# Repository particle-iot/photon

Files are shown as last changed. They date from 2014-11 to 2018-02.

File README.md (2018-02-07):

# Photon

The Photon is a tiny WiFi development kit based around USI's WM-N-BM-09 module. This module is a combination of Broadcom's BCM43362 WiFi radio and a STM32F205G microcontroller.

The Photon has a similar footprint and is as close to drop-in compatible as possible with the Spark Core.

### Some highlights of the USI module:

 1. IEEE 802.11b/g/n
 2. Soft AP mode - read smooth WiFi setup process
 3. STM32F205G
 	- 1 MB Flash
 	- 128KB RAM
 	- 120 MHz clock
 4. Measures 12mm x 11mm x 1.3mm

Compared to the Spark Core, the Photon introduces some additional hardware features and changes:

 1. Pin 3V3* is now replaced with VBAT. This pin can be used to power the internal RTC, backup registers and SRAM when the module is put in standby mode.
 2. Pins D1 and D2 can also be used for CAN communication (TX and RX respectively).
 3. Pin A3 now features a DAC (channel 2)
 4. Pin A6 is changed to DAC and exposes a DAC (channel 1).
 5. Pin A7 is changed to WKP (Wakeup). This pin can be used as a standard GPIO, ADC input, PWM or to WAKEUP (rising edge) the module from sleep/standby modes.

A detailed description of the pin mapping can be found in the pin-mapping folder of this repository.
* Sheet 1: Overview of the pin-out.
* Sheet 2: Detailed description of USI module pin-out and its internal mapping to the microcontroller and WiFi radio.

### Pin Descriptions:
- **VIN:** This is the power supply pin to the Photon with a voltage range of 3.6 to 5.5VDC (internally regulated down to 3.3VDC). When the Photon is powered via its USB port, this pin will *ouput* a voltage of approximately 4.7VDC. Why 4.7 and not 5? Well, the actual voltage will be the USB voltage, which is normally 5, minus the forward voltage drop (0.3V) of the protection diode.
- **RST:** This is an active-low reset pin for the Photon.
- **VBAT:** Supply to the internal RTC, backup registers and SRAM (1.8 to 3.3VDC).
- **3V3:** This pin is the output of the on-board regulator and is internally connected to the VDD of the WiFi module. When powering the Photon via VIN or the USB port, this pin will *output* a voltage of 3.3VDC. This pin can also be used to power the Photon directly (max input 3.3VDC). **NOTE:** When powering the Photon via this pin, do not put power on the VIN pin.
- **WKP:** This is an active-high input that allows you to wakeup the module from sleep/deep sleep modes. When not used as a WAKEUP, this pin can also be used as a digital GPIO, ADC input or PWM.
- **D0 - D7:** These are _digital only_ GPIO pins.
- **A0 - A5:** These can be used as digital GPIOs or as ADC inputs.
- **DAC:** This pin can be used as a digital GPIO, ADC input or as a DAC ouput.
- **RX:** Primarily used as UART RX, but can also be used as a digital GPIO, ADC input or PWM.
- **TX:** Primarily used as UART TX, but can also be used as a digital GPIO, ADC input or PWM.

Please review the spreadsheet under the pin-mapping folder to better understand the alternate functions of the GPIO pins.

### Eagle (schematic and pcb layout):
Under the `eagle` folder, you'll find the history of Photon designs.
 1. **cam-drc:** Contains CAM Jobs (for creating gerbers) and DRC (Design Rule) files.
 2. **photon_v001:** The initial photon design.  This version of the design uses the same dimensions as the Spark Core and provides through-hole headers for mounting.
 3. **photon_v010:** Several versions later, numerous tweaks and additions to the schematic, smaller less blinding RGB LED, aligned D7 LED with D7 pin, new SMPS voltage regulator, castellated and non-castellated have been merged, new slightly larger higher gain antenna, Bluetooth Co-existance pins are broken out to pads for a 1.27mm pitch (0.050") connector, pads on the bottom side of the board were added for the RGB LED, and MODE button connections and are centered on the 0.1" grid, and RF switch for software selection of u.FL vs Chip Ant. RF Test board's for versions are included to make tuning of matching components in RF stage easier. There is a second Photon design here with antenna scooted to the left 0.027" to give more clearance between D0 pin and antenna.  C1 in Pi filter was removed to make room for this tighter layout.
 4. **photon_v019:** Several more versions later, numerous tweaks and additions to the schematic, WM-N-BM-09 soldermask updated, added some GND vias, MODE button label changed to SETUP, increased width of top and bottom (short) sides of PCB 20 mils to allow for v-score (overall board height is now 1.44"), SETUP and RESET buttons and RGB led are not centered on the 0.1" grid anymore but they are all still inline with each other, RF switch was changed to a much smaller 1mm version, 0201 dc blocking capacitors added to all RF ports, Pi filter was tuned to match antenna to 50 ohm impedance, half of the pads on the bottom were enlarged to 60 mils square, added fabrication spec.

# License

Designed by Particle. Distributed under a Creative Commons Attribution, Share-Alike license.
Development kits based on this product should be distributed under a similar license.
Commercial products using the Photon as a reference design need not comply with this license; further questions can be sent to hello@particle.io.
Check license.txt for more information.

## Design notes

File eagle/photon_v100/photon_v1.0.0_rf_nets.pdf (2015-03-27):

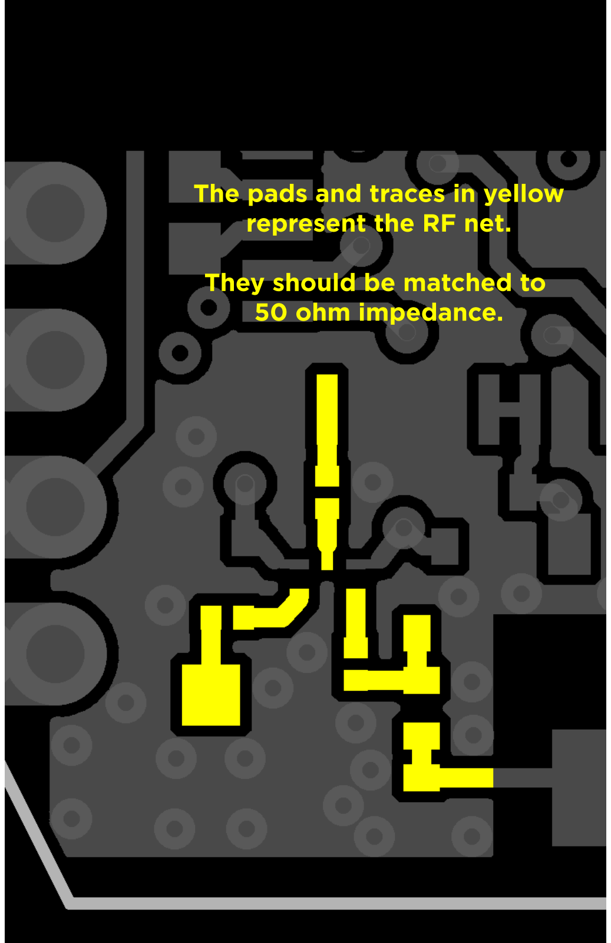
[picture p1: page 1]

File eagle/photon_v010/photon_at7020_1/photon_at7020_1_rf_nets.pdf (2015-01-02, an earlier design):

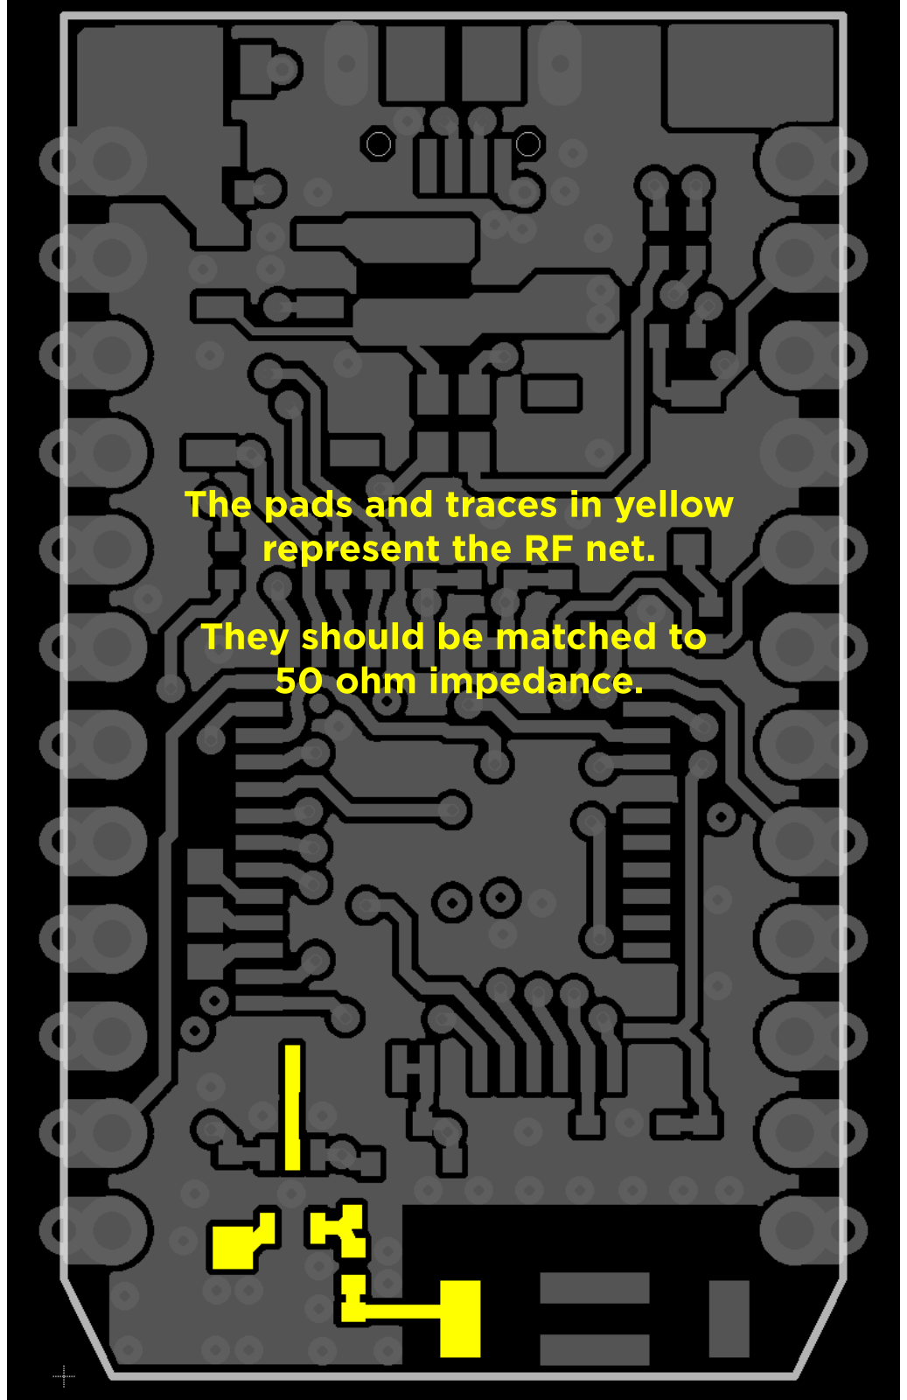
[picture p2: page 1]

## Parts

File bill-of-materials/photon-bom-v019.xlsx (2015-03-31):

Spark |  | Photon
BOM Version |  | v0.1.9
Qty | Device | Minimum Specification | Package/Case | Part Designator | MFG. | MFG. PN
1 | ANTENNA | 2.4GHz, Ceramic | 5.0mm × 2.0mm x 2.6mm | ANT1 | Advanced Ceramic X Johnason | AT7020-E3R0HBA 2450AT43B100E
2 | CERAMIC CAPACITOR | 22uF, Ceramic, 6.3V, 10%, X5R | 0603 | C4, C5 | Samsung | CL10A226MQ8NRNC
6 | CERAMIC CAPACITOR | 0.1uF, Ceramic, 6.3V, 10%, X5R | 0402 | C6, C7, C8, C10, C12, C16 | RongFu | 0402B104K01A
2 | CERAMIC CAPACITOR | 100pF, Ceramic, 6.3V, 10%, X5R | 0402 | C2, C3 | Fenghua | 0402CG101J500NT
4 | CERAMIC CAPACITOR | 10uF, Ceramic, 6.3V, 10%, X5R | 0603 | C9, C11, C13, C15 | Sumsung | CL10A106MQ8NNNC
3 | CERAMIC CAPACITOR (RF) | 10pF, Ceramic, 6.3V, 10%, X5R | 0402 | C16, C17, C18 | Murata | GJM1555C1HR80BB01D
1 | CONNECTOR | USB Micro-B with tabs and slots | USB-MICROB | X1 | Kaweei | CMCUSB-5BFM2G-01-D
1 | CONNECTOR | uFL Connector | SMD | X2 | Kaweei | P1163-0140R
2 | HEADER | Single String, 1.2" Mating Length | 0.1" 12-pin | JP1, JP2 | Kaweei | CP25411-12G-S116-A
1 | DIODE | Diode, Schottky, 30V, 3A | DO-220AA | D1 | Vishay | SS3P3-M3/84A
1 | DIODE (LED) | Blue, SMD | 0603 | LED1 | Everlight | 19-217/BHC-ZL1M2RY/3T
1 | DIODE (LED) | LED RGB, Common Anode, Diffused, SMD | 4-PLCC (2.0mm x 2.0mm) | LED2 | Cree | CLVBA-FKA-CAEDH8BBB7A363
1 | INDUCTOR | 2.2uH, 1.5A | 3mm x 3mm | L5 | Taiyo Yuden | NR3015T2R2M
1 | INDUCTOR (RF) | 3.9nH, RF inductor | 0402 | L4 | Johanson | L-07C3N9SV6T
1 | INDUCTOR (RF) | 4.7nH, RF inductor | 0402 | L1 | Johanson | L-07C4N7SV6T
1 | INDUCTOR (RF) | 6.8nH, RF inductor | 0402 | L3 | Johanson | L-07C6N8JV6T
1 | WI-FI + MCU | Broadcom Wi-FI + STM32 MCU | Custom USI SMD | U1 | USI | WM-N-BM-09
1 | RF SWITCH | RF Switch SPDT | UQFN-6 (1x1mm) | U3 | Skyworks | SKY13350-385LF
1 | POWER REGULATOR | 3.3V,1.5MHz, 600mA, High Efficiency PWM Step-Down DC/DC Converter | SOT23-5 | U2 | Richtek | RT8008-33GB
1 | RESISTOR | 100K, 5% | 0402 | R4 | Fenghua | RC-02W104FT
2 | RESISTOR | 22R, 5% | 0402 | R5, R6 | Fenghua | RC-02W220JT
1 | RESISTOR | 10K, 5% | 0402 | R8 | Fenghua | RC-02W103JT
4 | RESISTOR | 1K, 5% | 0402 | R9, R10, R11, R12 | Fenghua | RC-02W102JT
2 | SWITCH | Button, 160gf | 3.6mm x 3.1mm | SETUP, RESET | Haoyu | TS-1185A-C

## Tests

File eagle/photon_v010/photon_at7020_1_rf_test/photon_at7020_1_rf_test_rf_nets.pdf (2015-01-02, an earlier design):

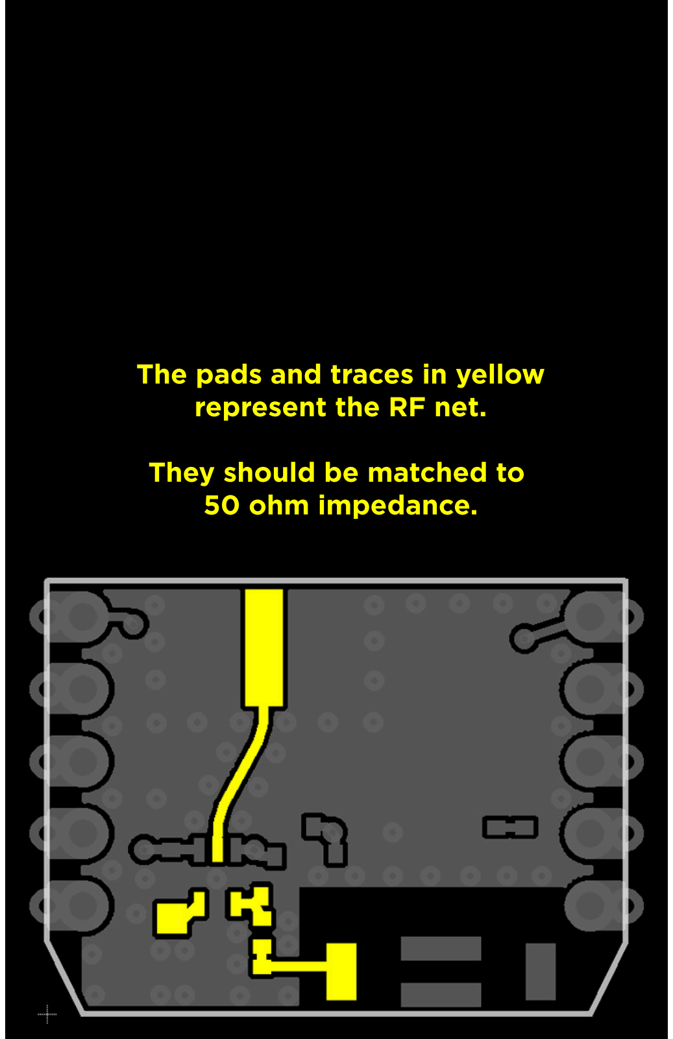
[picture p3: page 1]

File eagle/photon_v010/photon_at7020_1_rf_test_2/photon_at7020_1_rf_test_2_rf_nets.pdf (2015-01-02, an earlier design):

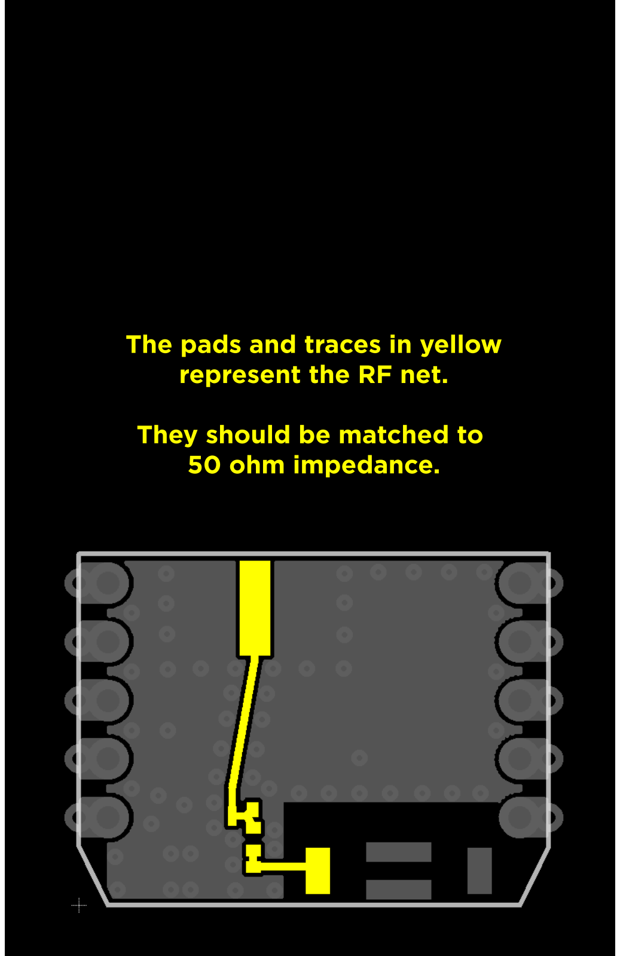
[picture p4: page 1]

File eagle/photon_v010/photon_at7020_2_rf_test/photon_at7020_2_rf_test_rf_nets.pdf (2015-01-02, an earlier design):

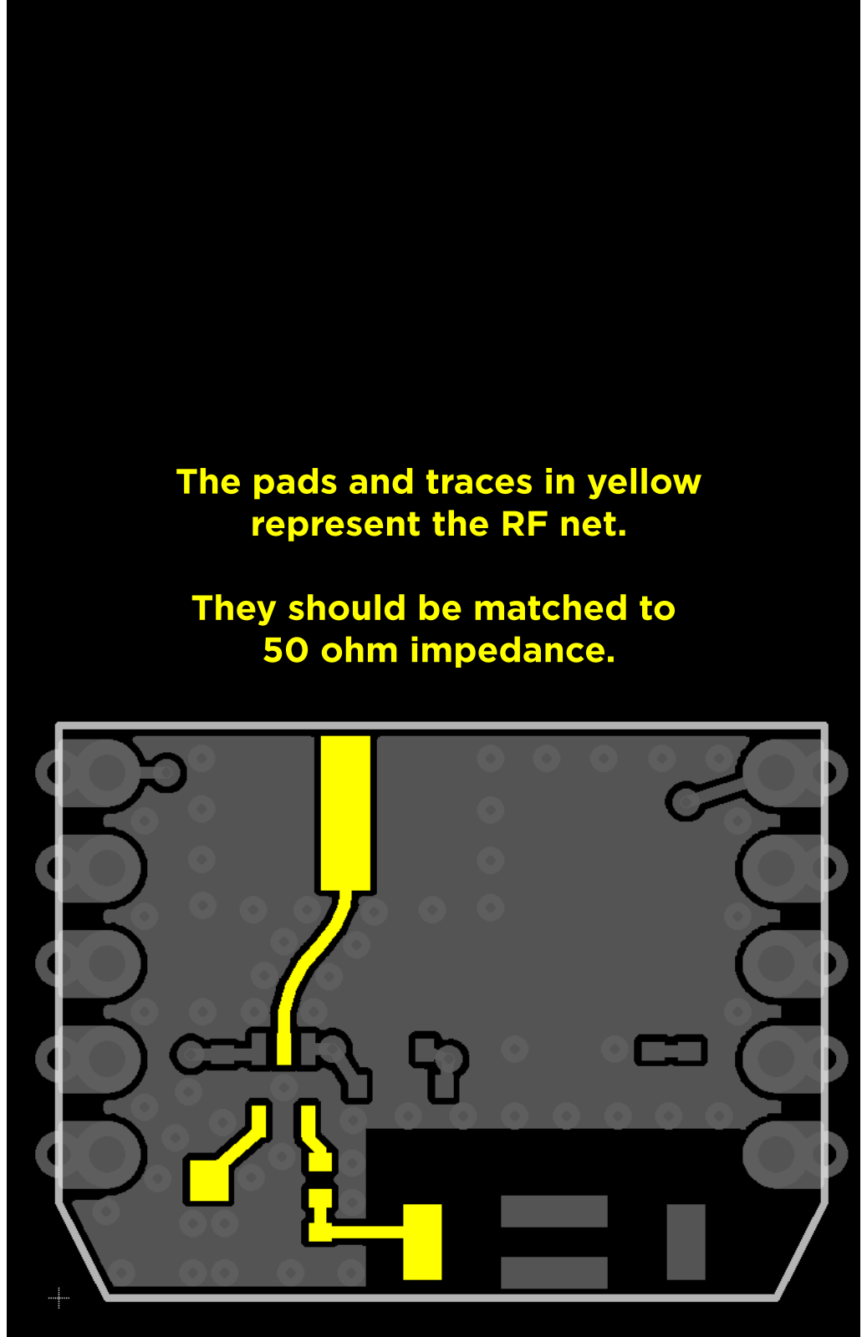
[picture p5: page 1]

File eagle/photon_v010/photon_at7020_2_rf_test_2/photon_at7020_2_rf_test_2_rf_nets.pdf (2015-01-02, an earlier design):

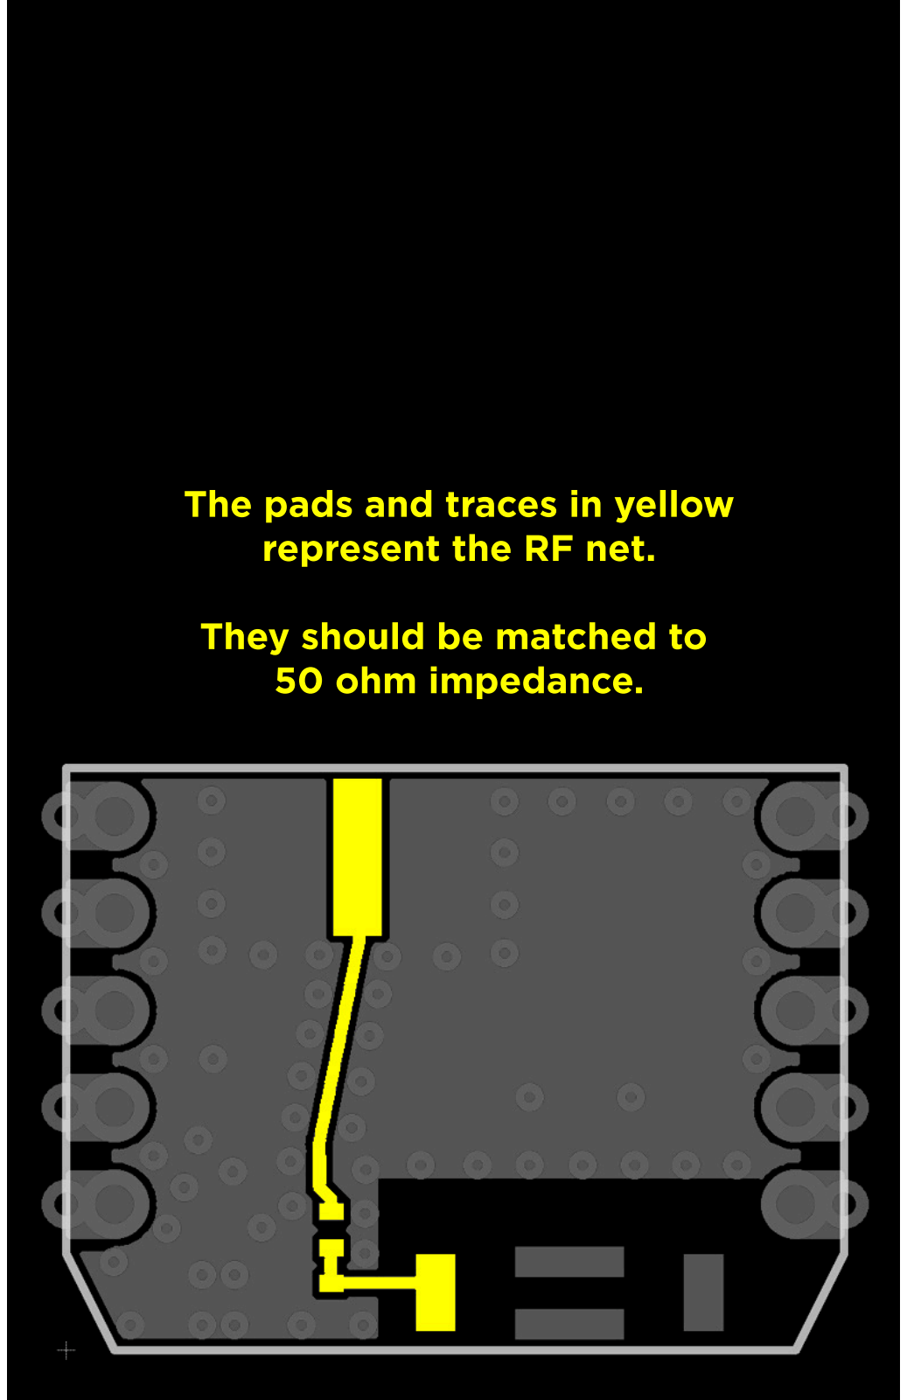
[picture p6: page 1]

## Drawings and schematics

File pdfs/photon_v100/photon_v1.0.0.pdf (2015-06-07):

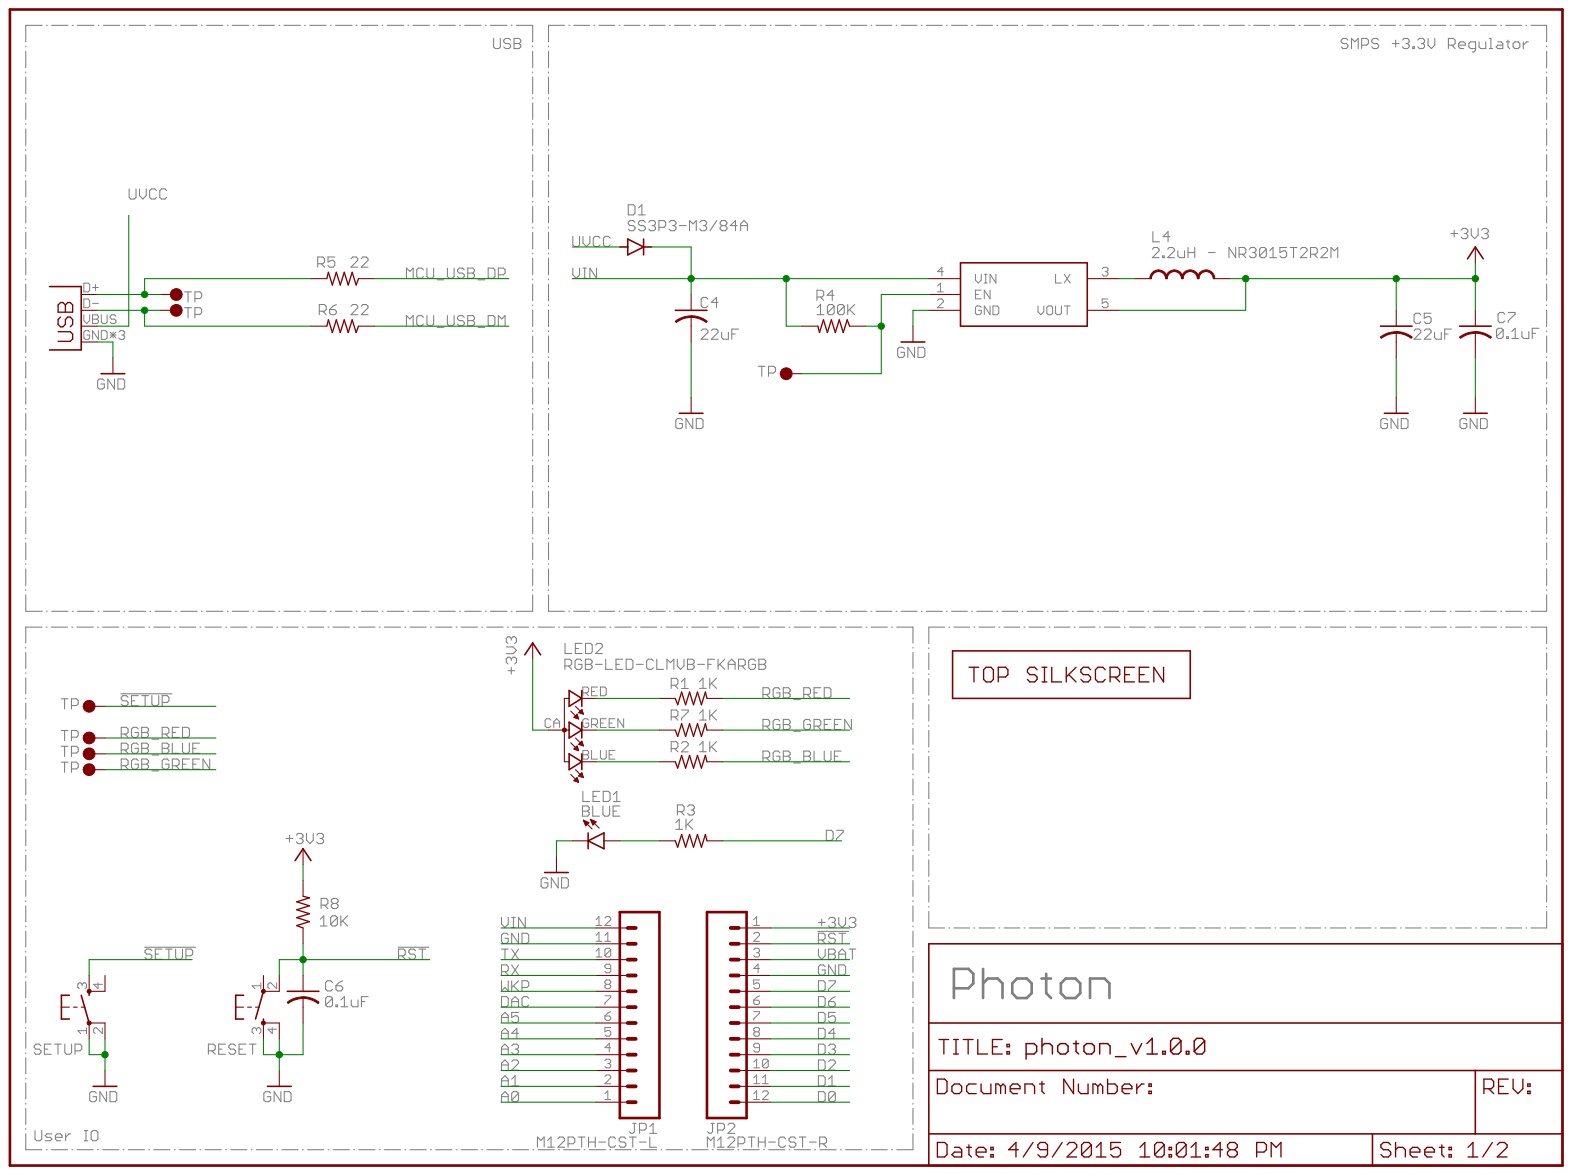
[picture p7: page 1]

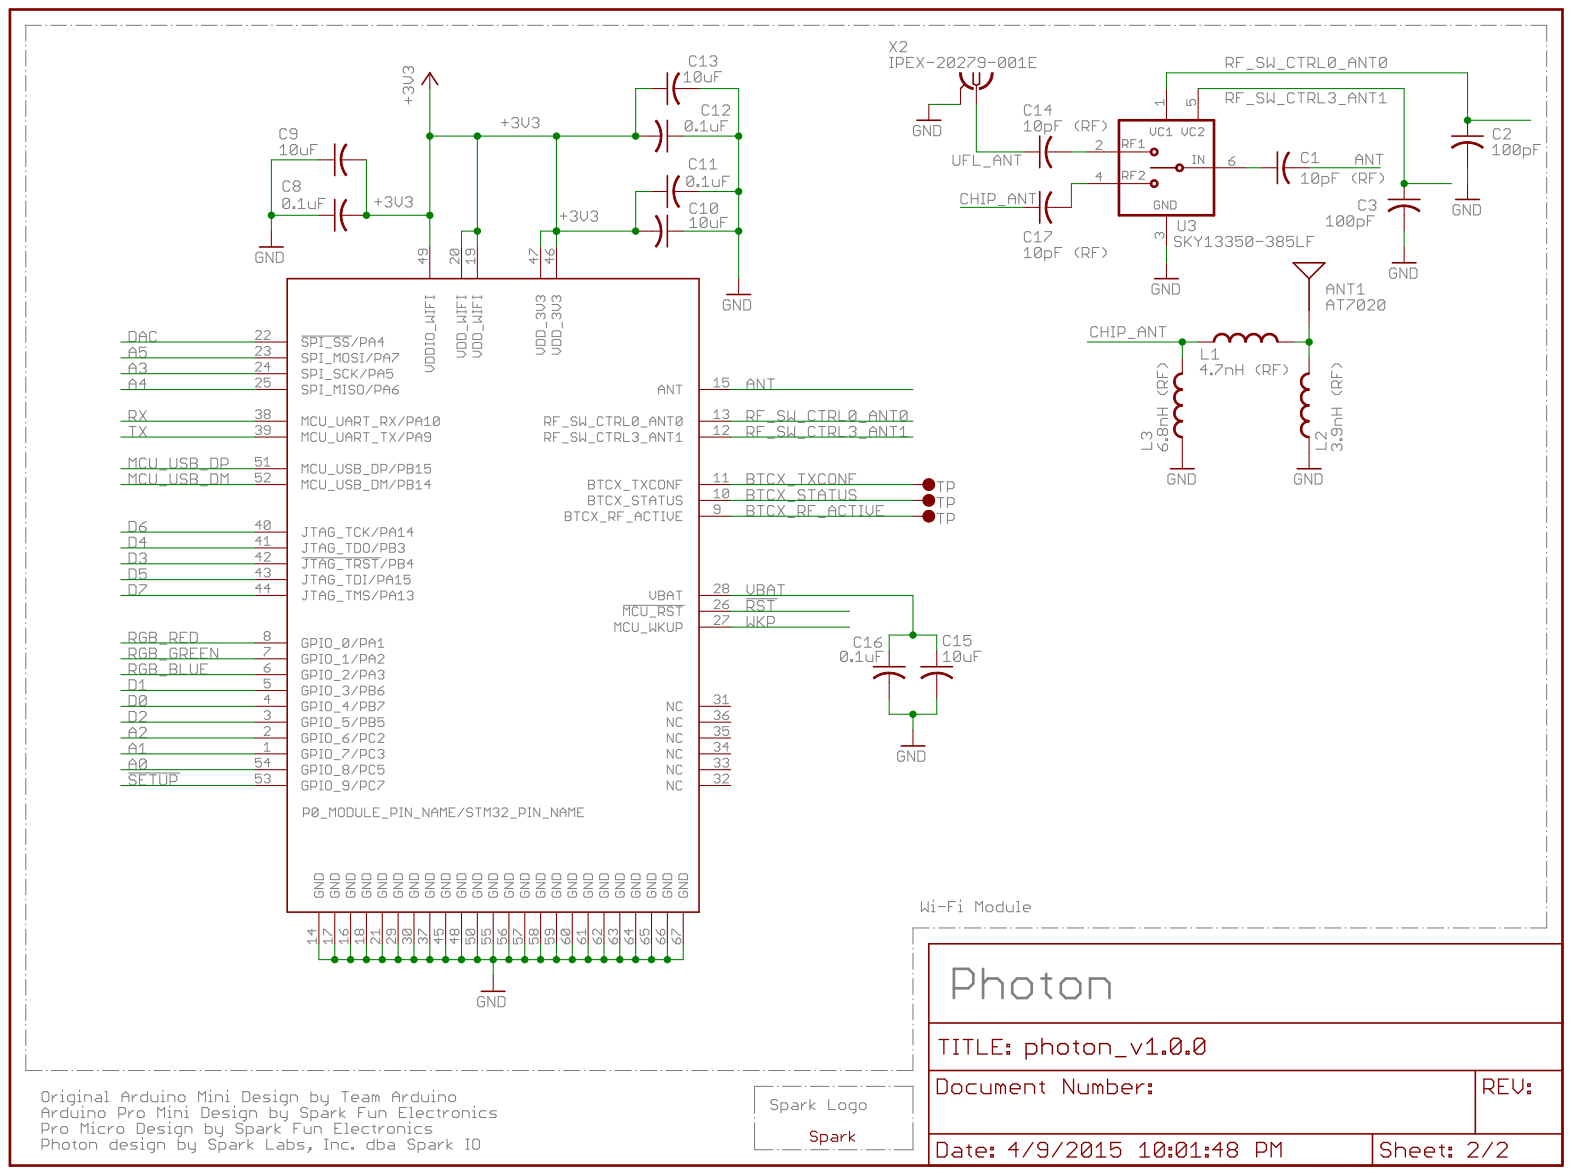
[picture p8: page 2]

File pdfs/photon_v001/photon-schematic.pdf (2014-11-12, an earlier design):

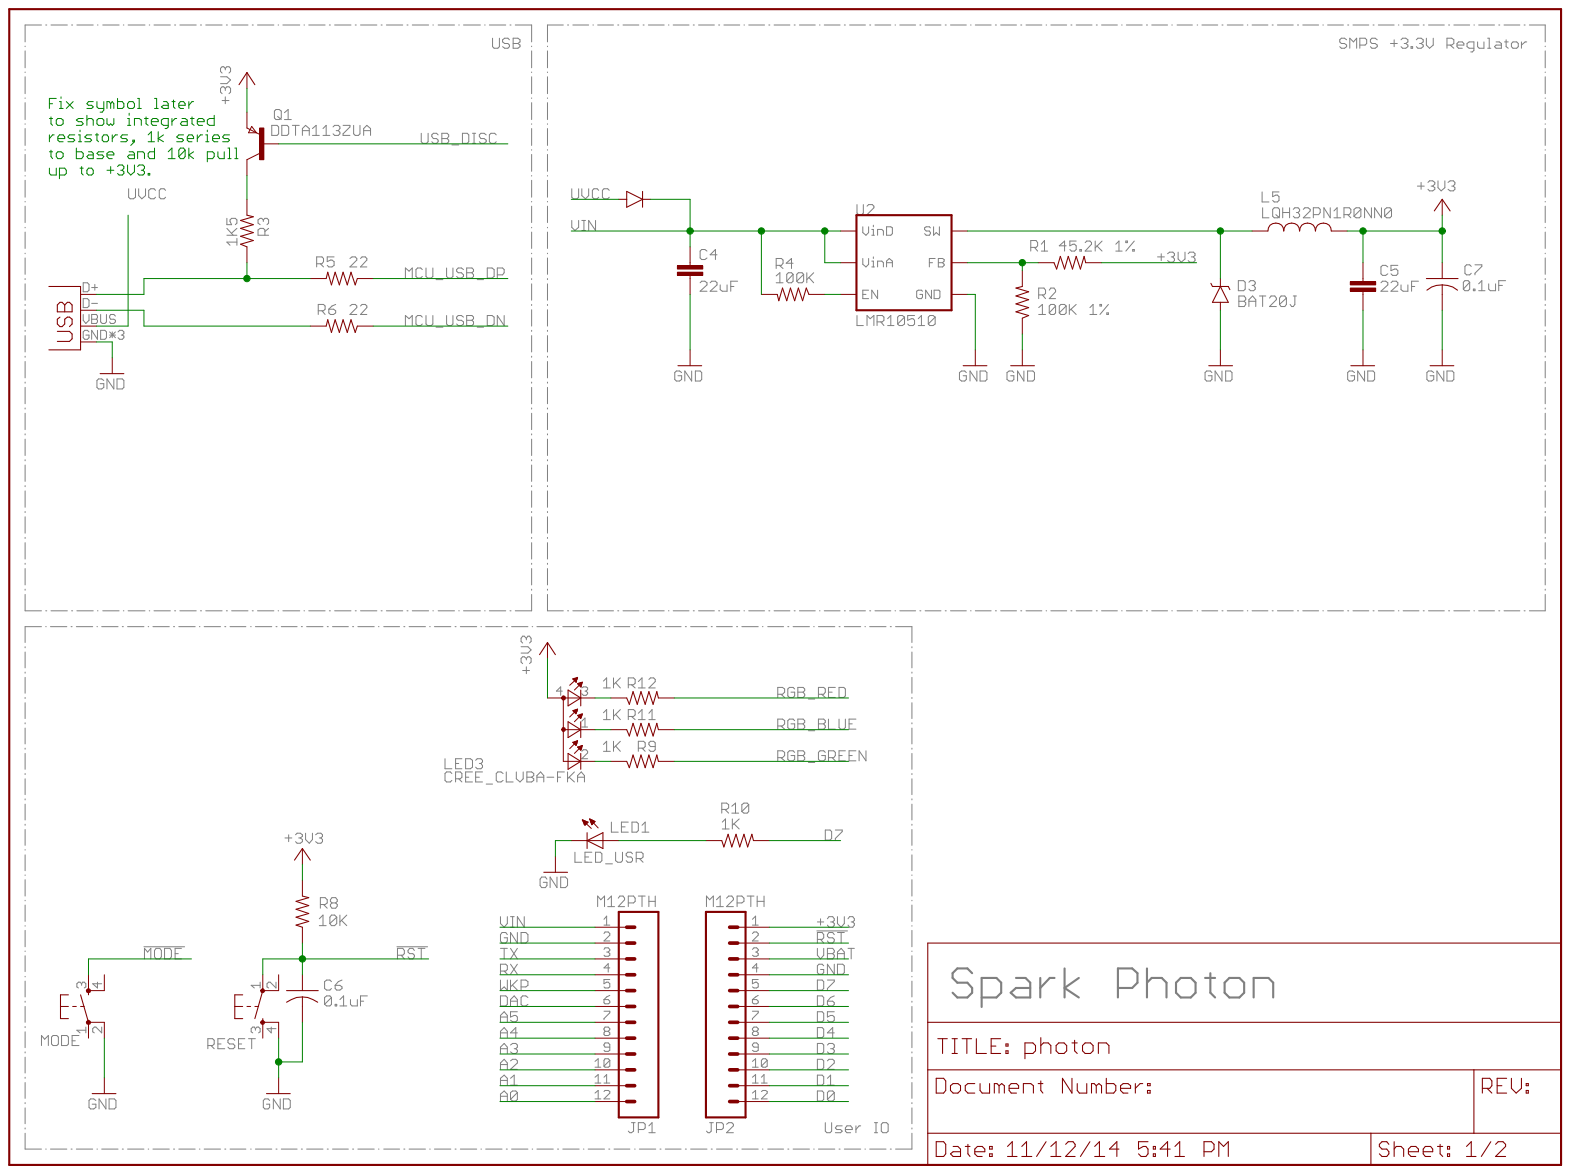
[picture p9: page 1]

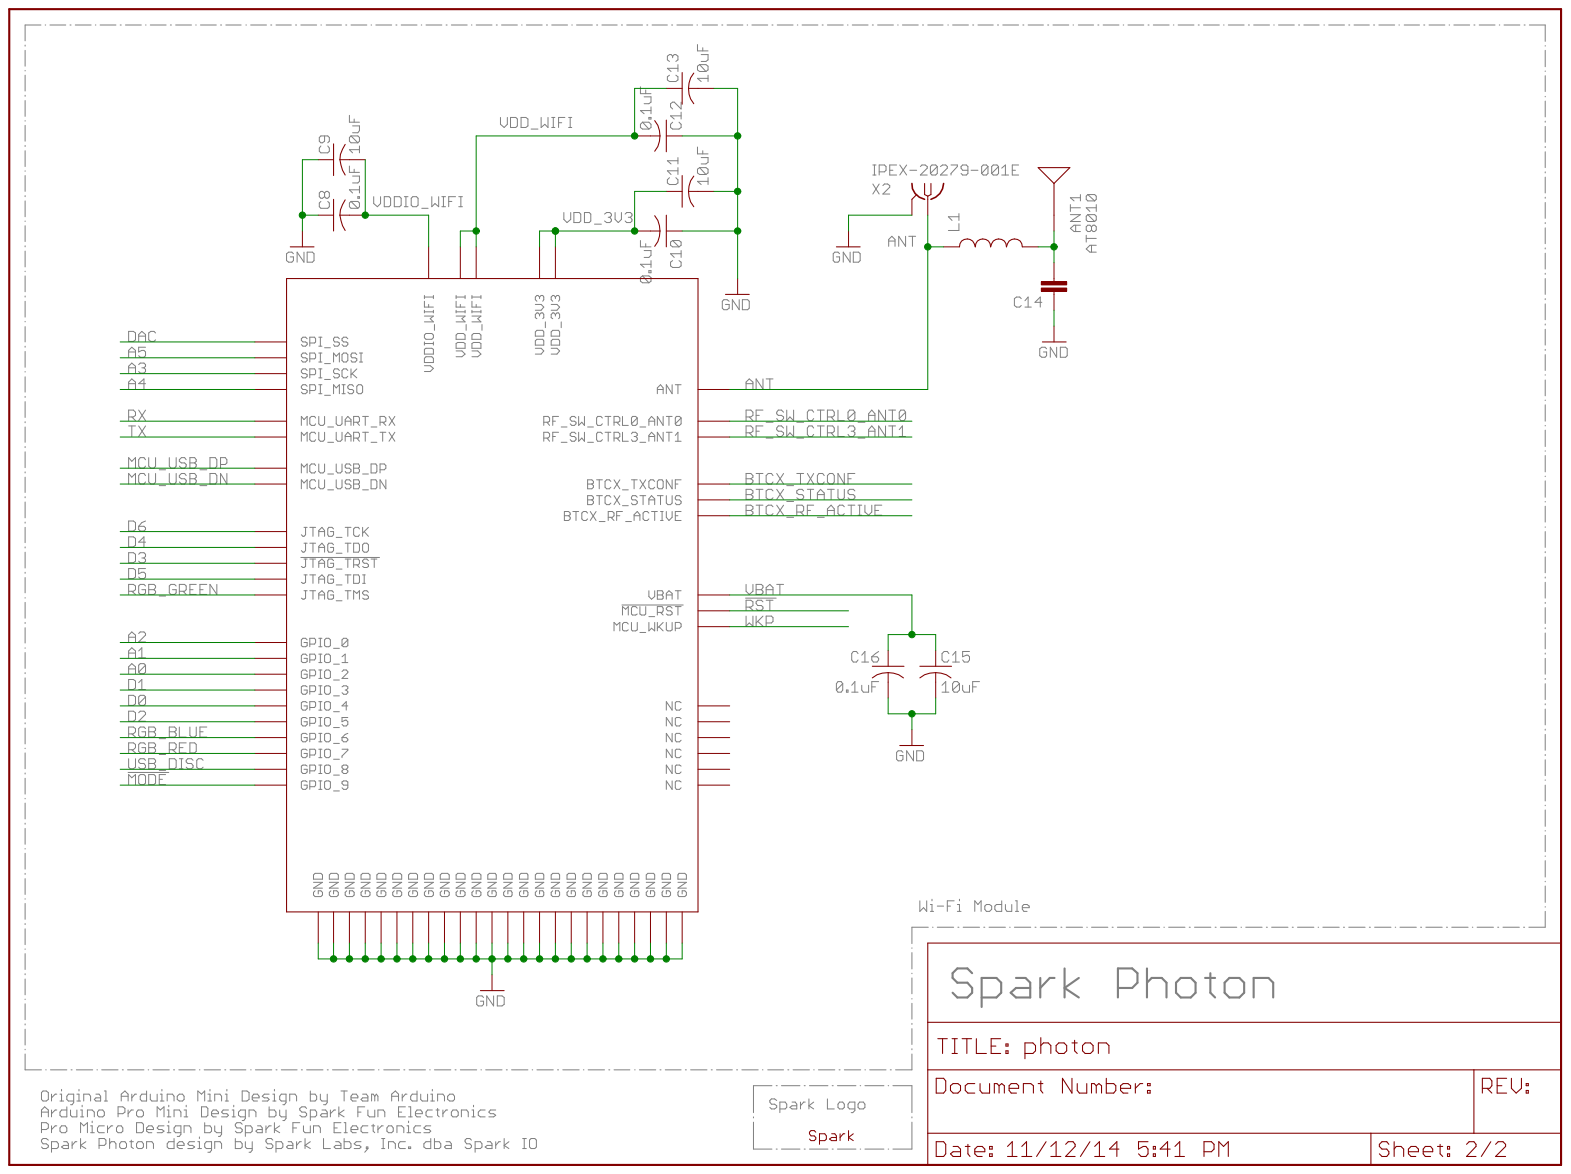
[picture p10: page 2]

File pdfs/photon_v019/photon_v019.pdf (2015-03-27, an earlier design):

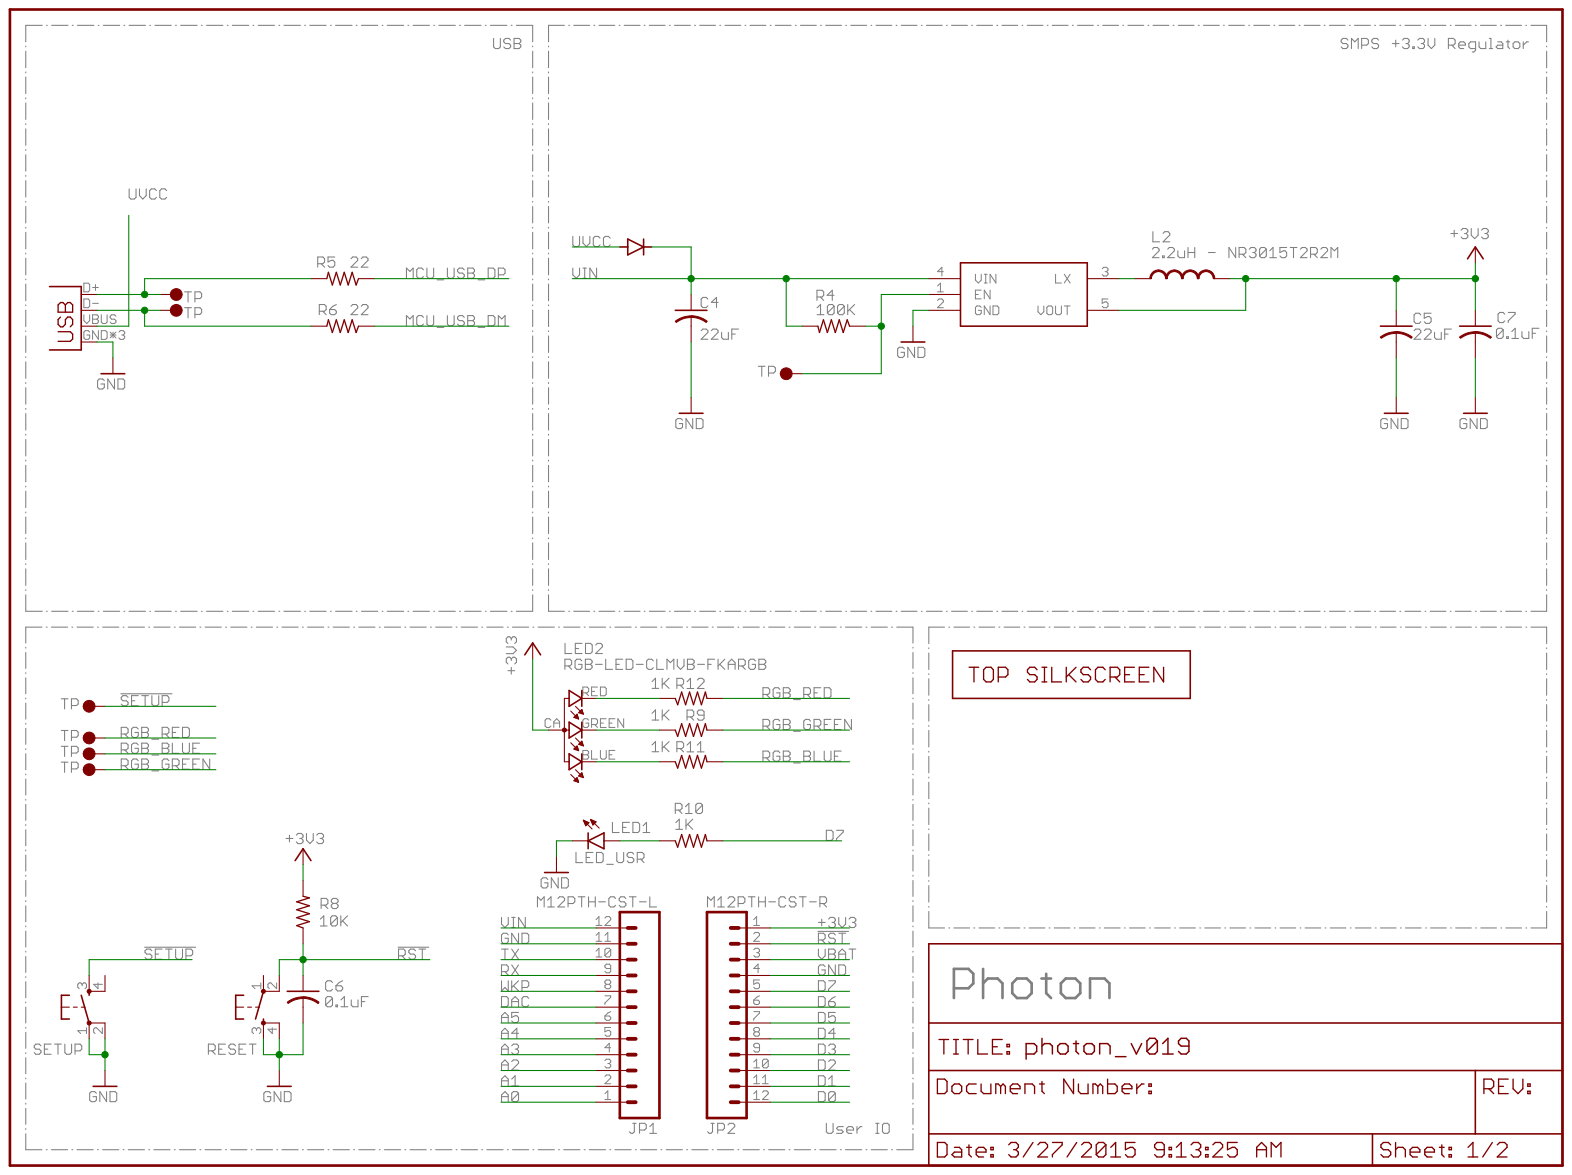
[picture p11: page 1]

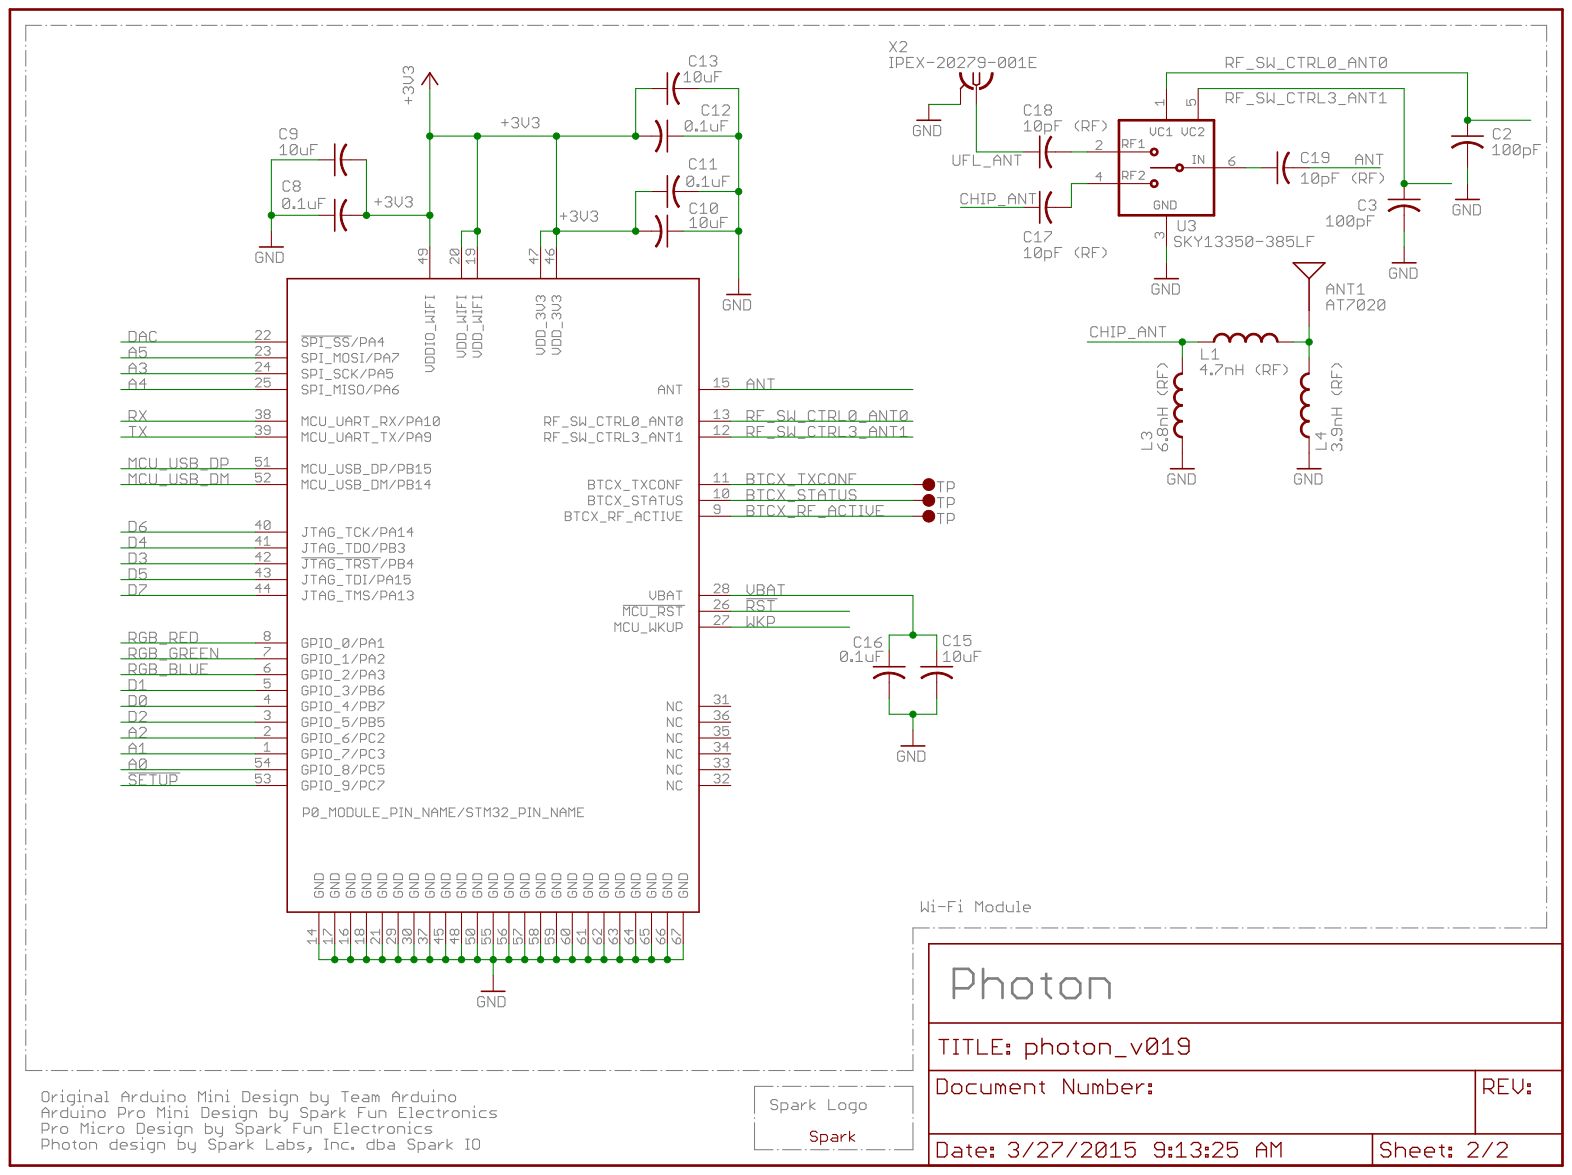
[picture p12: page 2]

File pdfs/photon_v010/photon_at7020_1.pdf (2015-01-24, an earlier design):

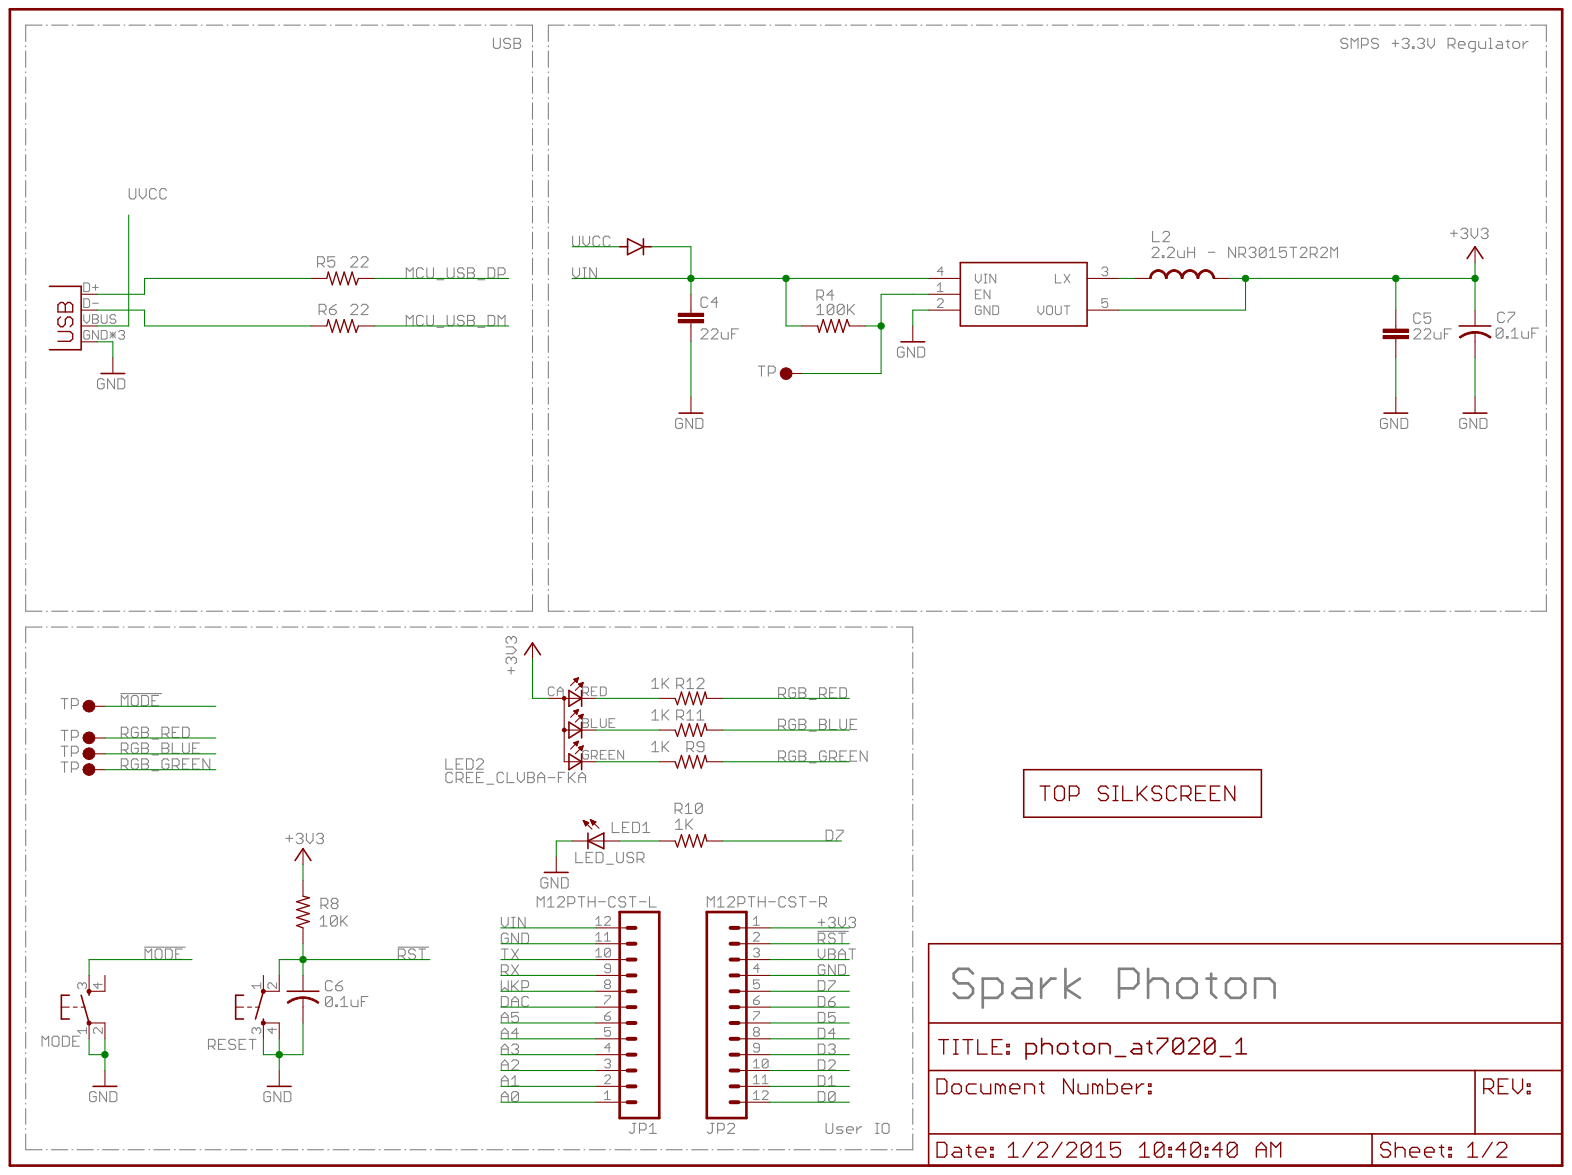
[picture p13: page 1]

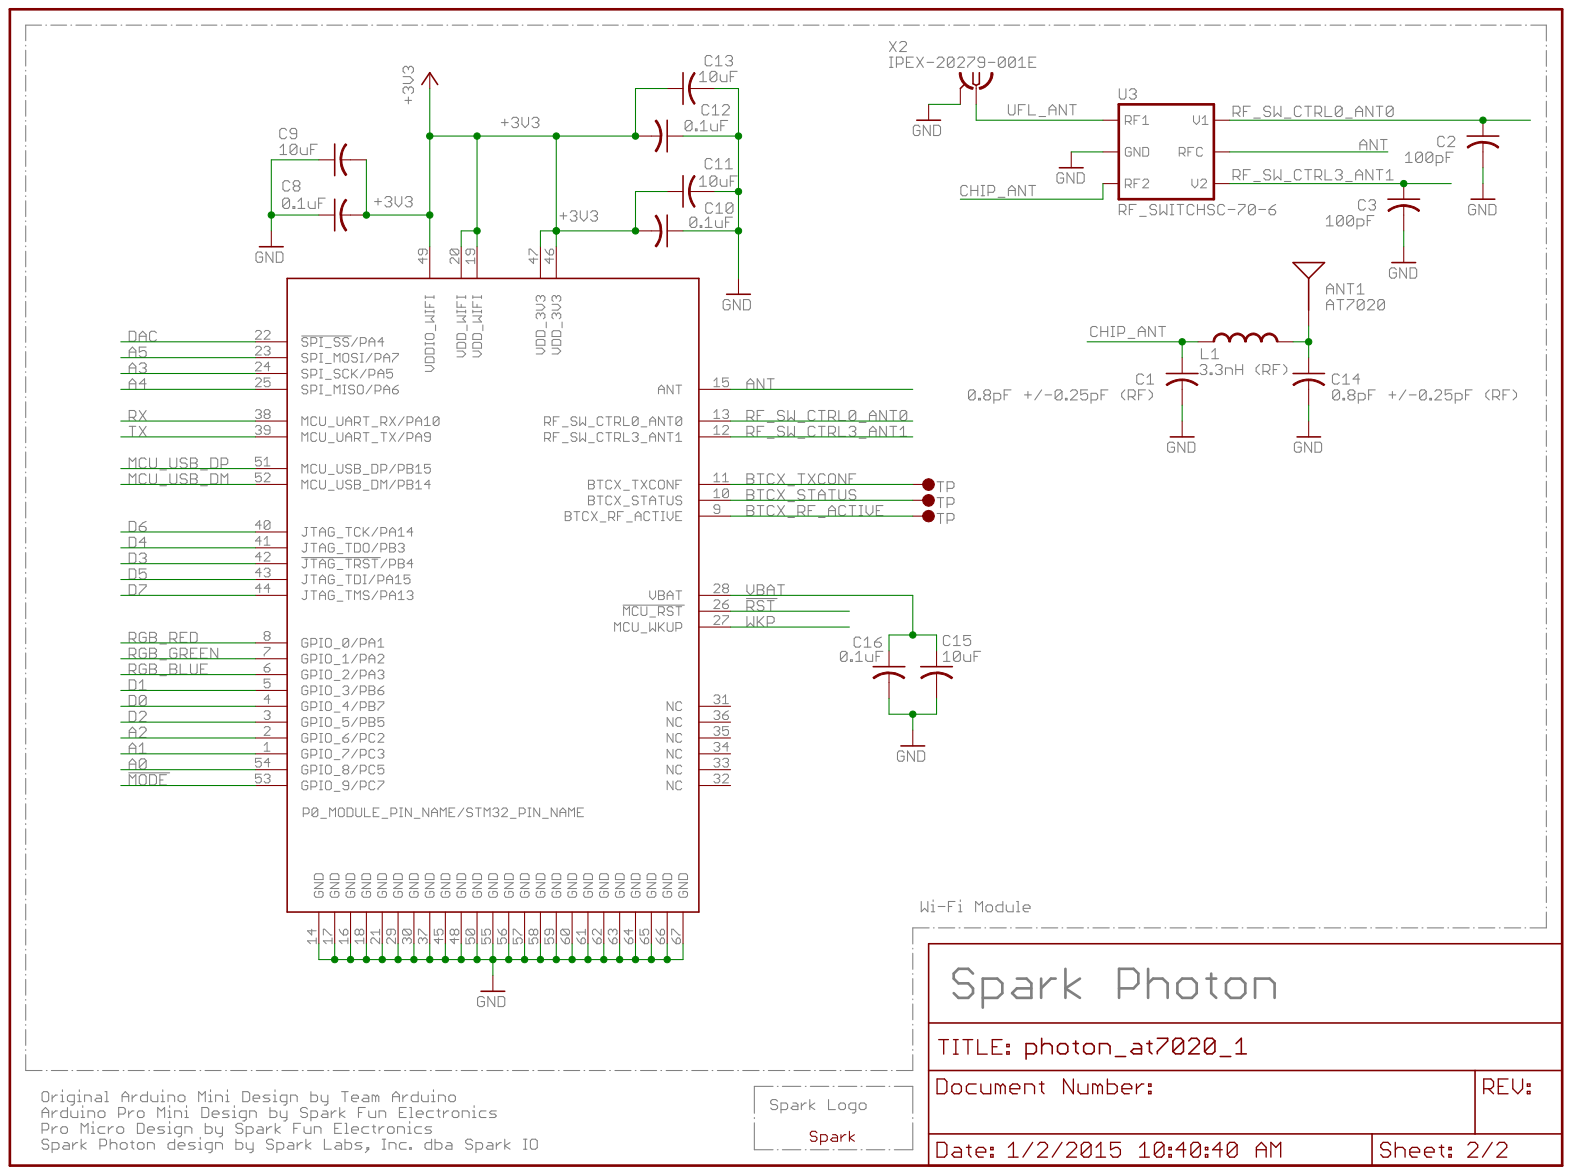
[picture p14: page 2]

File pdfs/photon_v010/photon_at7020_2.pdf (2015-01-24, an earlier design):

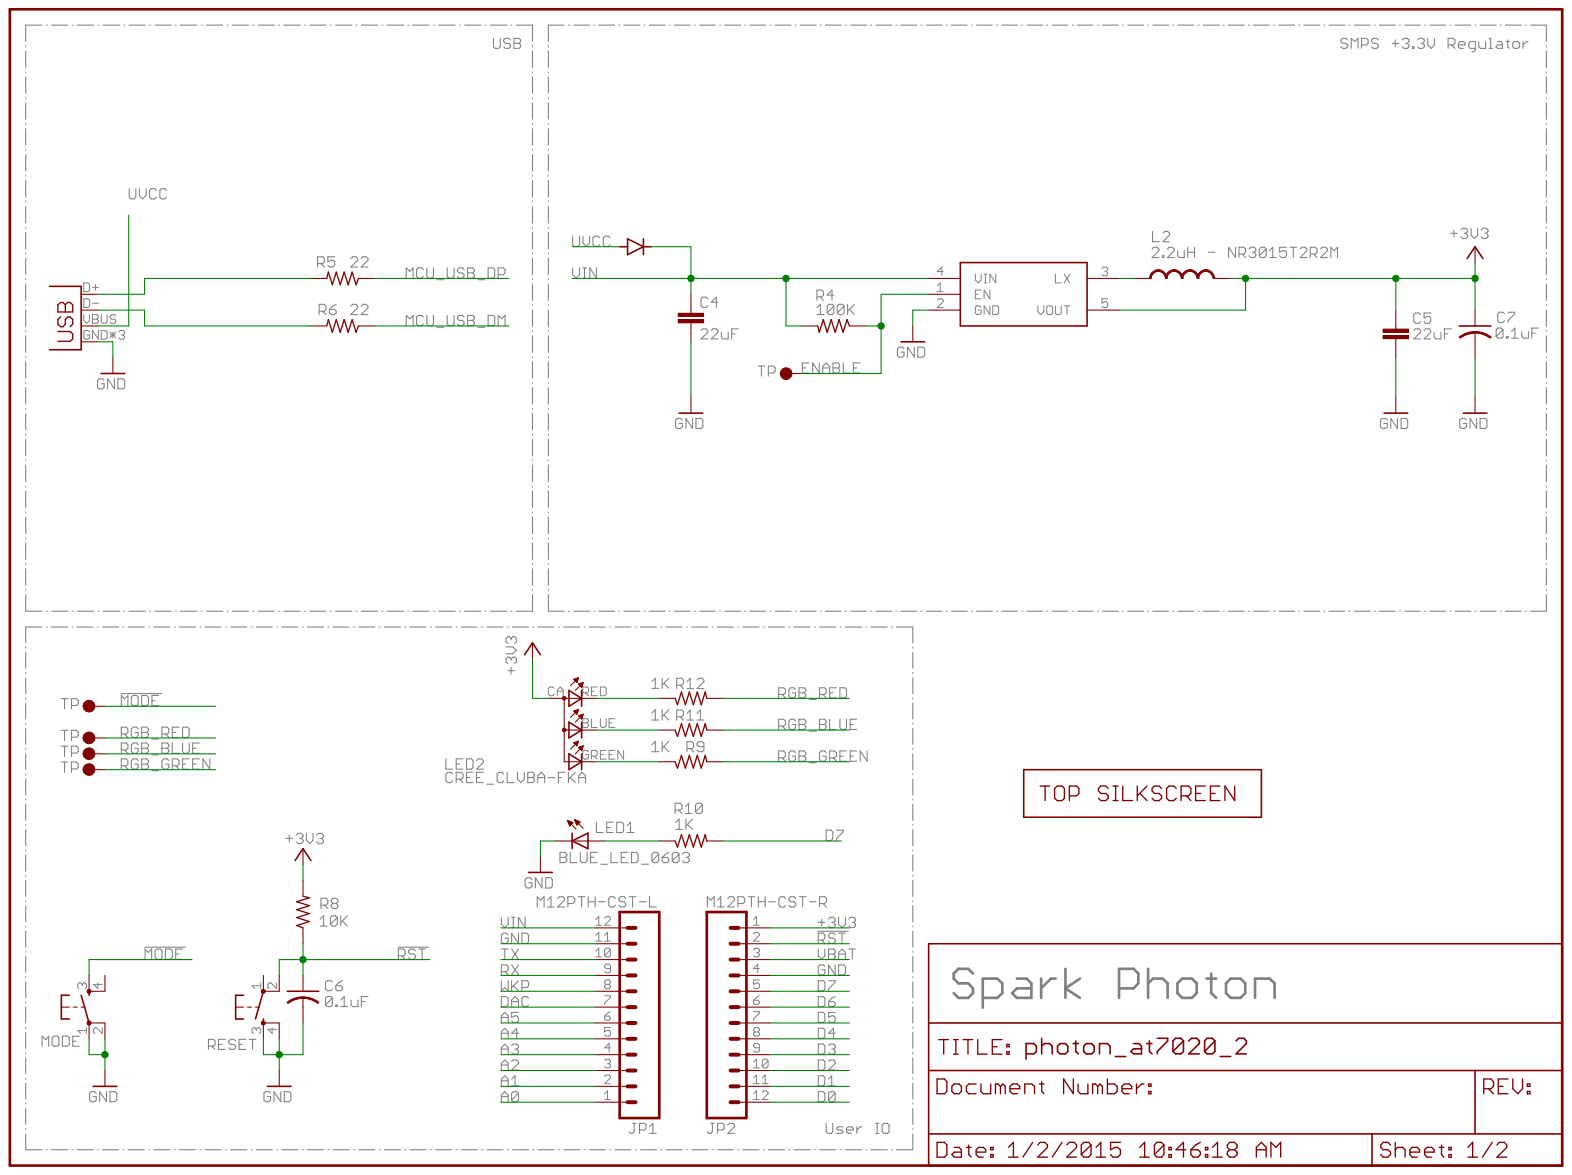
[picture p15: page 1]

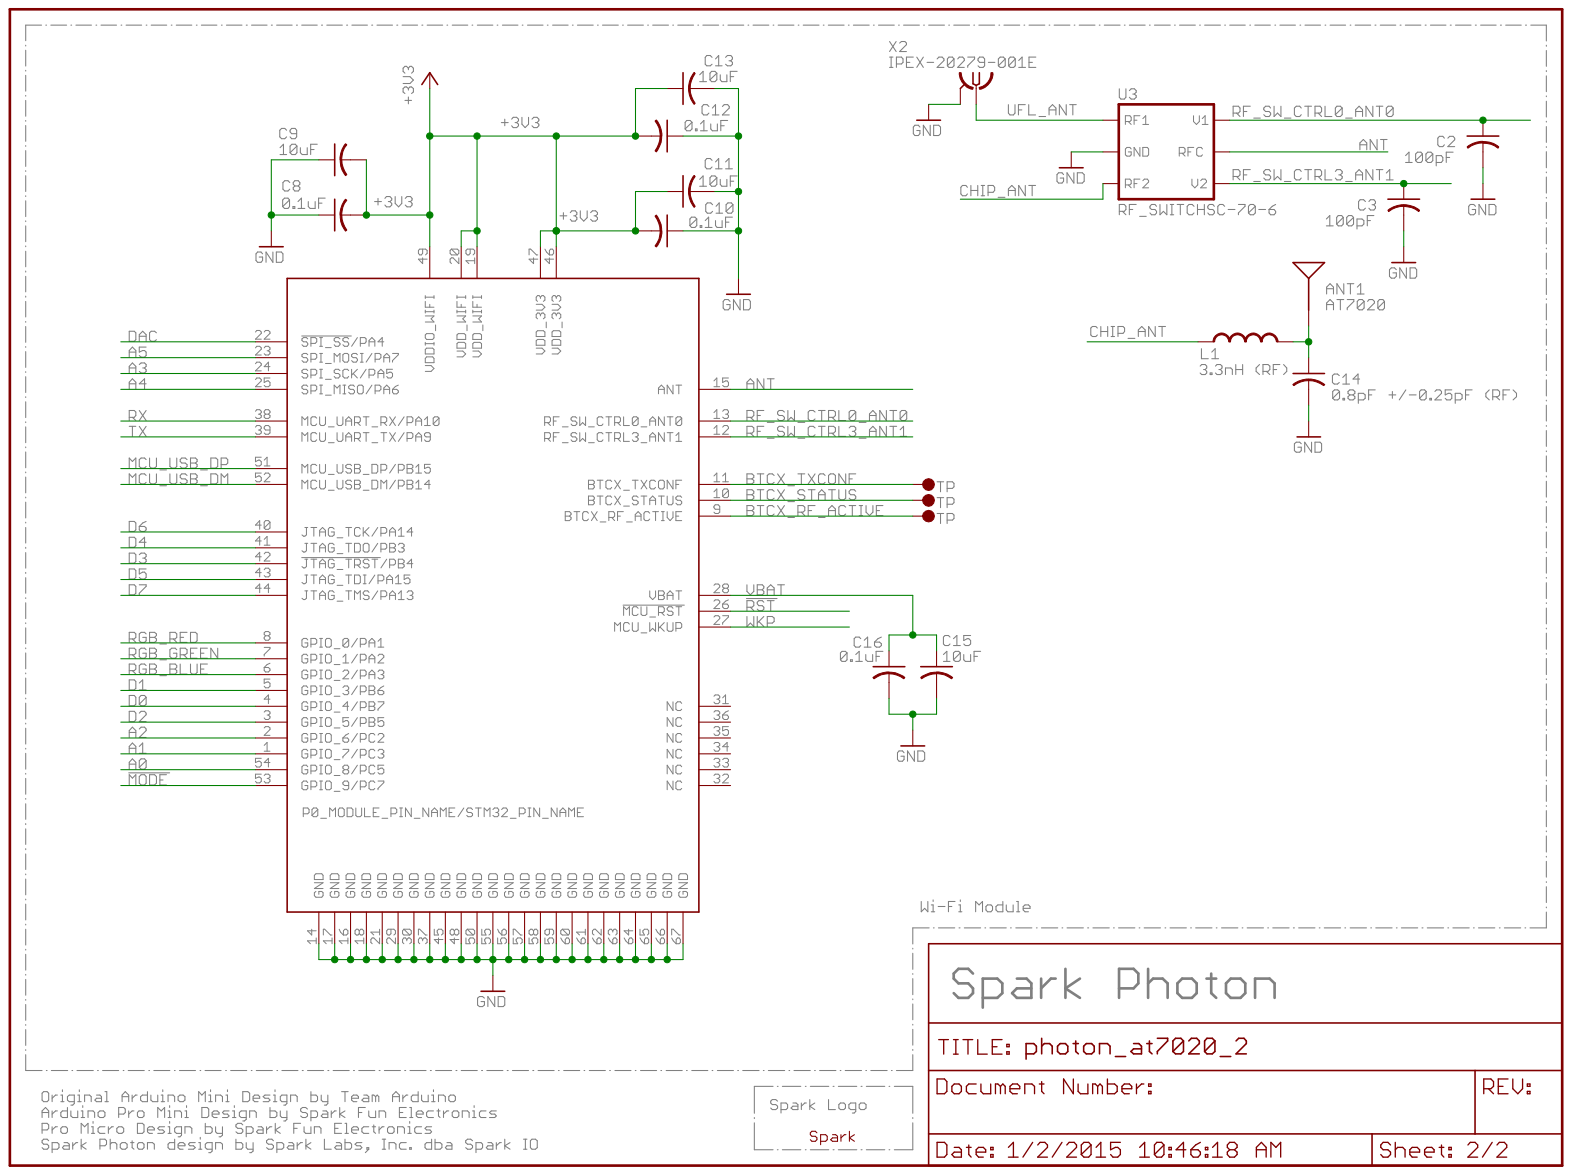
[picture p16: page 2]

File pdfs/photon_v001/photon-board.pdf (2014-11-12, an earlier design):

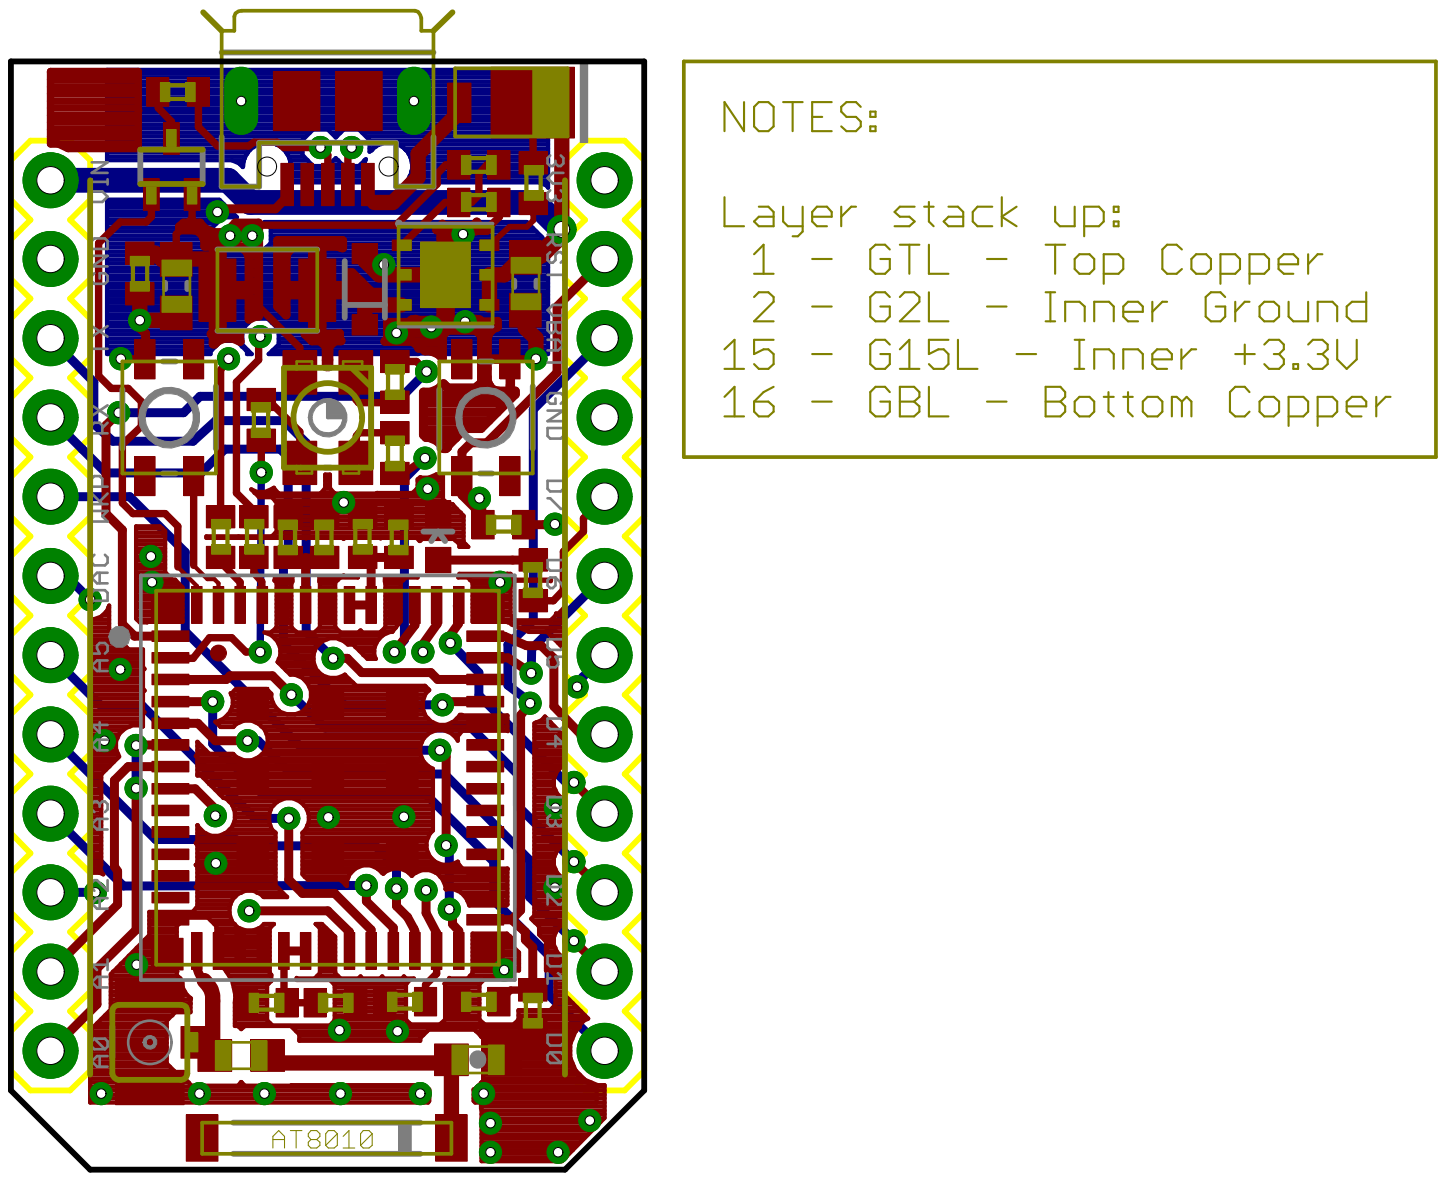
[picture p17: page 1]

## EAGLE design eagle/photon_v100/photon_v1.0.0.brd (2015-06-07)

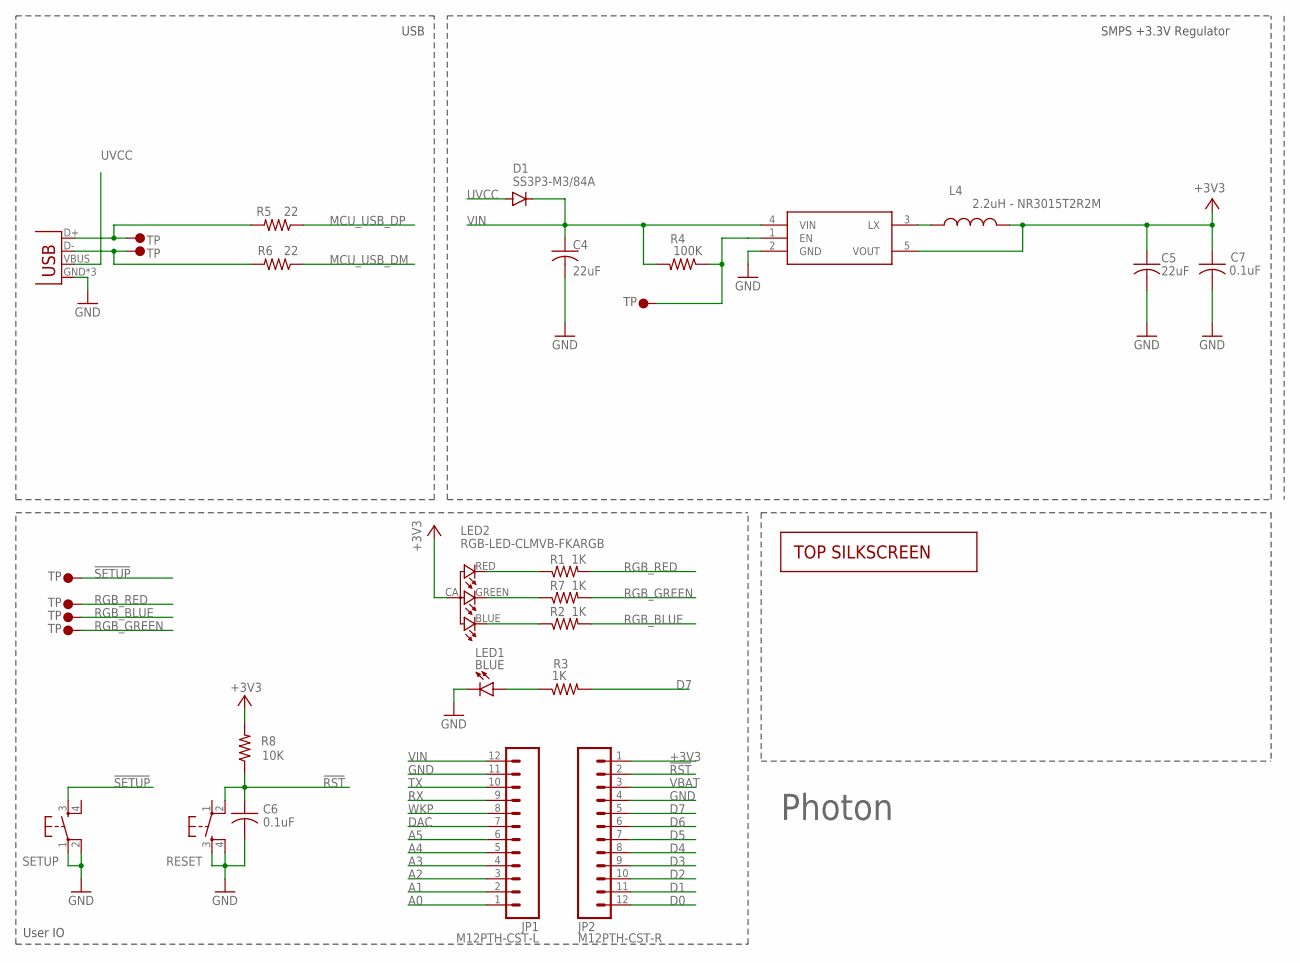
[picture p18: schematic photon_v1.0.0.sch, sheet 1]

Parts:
C4, C5: 22uF; C0603_B
C6, C7: 0.1uF; C0402_B
D1: SS3P3-M3/84A; DIODE-DO-220AA(SMP)
JP1: M12PTH-CST-L; 1X12-CASTELLATED
JP2: M12PTH-CST-R; 1X12-CASTELLATED
L4: 2.2uH - NR3015T2R2M; INDUCTOR-NR3015
LED2: RGB-LED-CLMVB-FKARGB; PLCC4-2MM-RGB
LED_USR: BLUE; LED-0603-NO-SS
R1, R2, R3, R7: 1K; R0402_B
R4: 100K; R0402_B
R5, R6: 22; R0402_B
R8: 10K; R0402_B
RESET: KMR211GLFS; TACTILE_SWITCH_SMD
SETUP: KMR211GLFS; TACTILE_SWITCH_SMD
U$1: PHOTON-TOP-SS2; PHOTON-TOP-SS-2
U$3, U$12, U$13, U$14: TP3; TP60_BOT
U$5, U$6, U$7: TP1; TP35_BOT
U$11: R8008-33; SOT23-5
X1: USB-MICROB; USB-MICROB-SLOT-HOLE

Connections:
!RST: C6.1, JP2.2, R8.1, RESET.2; also elsewhere on the board
!SETUP: SETUP.3, U$3.P$1; also elsewhere on the board
+3V3: C5.1, C7.1, JP2.1, L4.2, LED2.CA (1), R8.2, U$11.5 (VOUT); also elsewhere on the board
A0: JP1.1 (12); also elsewhere on the board
A1: JP1.2 (11); also elsewhere on the board
A2: JP1.3 (10); also elsewhere on the board
A3: JP1.4 (9); also elsewhere on the board
A4: JP1.5 (8); also elsewhere on the board
A5: JP1.6 (7); also elsewhere on the board
D0: JP2.12; also elsewhere on the board
D1: JP2.11; also elsewhere on the board
D2: JP2.10; also elsewhere on the board
D3: JP2.9; also elsewhere on the board
D4: JP2.8; also elsewhere on the board
D5: JP2.7; also elsewhere on the board
D6: JP2.6; also elsewhere on the board
D7: JP2.5, R3.2; also elsewhere on the board
DAC: JP1.7 (6); also elsewhere on the board
GND: C4.2, C5.2, C6.2, C7.2, JP1.11 (2), JP2.4, LED_USR.C1 (C), RESET.3, RESET.4, SETUP.1, SETUP.2, U$11.2 (GND), X1.GND, X1.MT1 (GND), X1.MT2 (GND); also elsewhere on the board
LED1: LED_USR.A1 (A), R3.1
MCU_USB_DM: R6.1; also elsewhere on the board
MCU_USB_DP: R5.1; also elsewhere on the board
unnamed: R5.2, U$13.P$1, X1.D+
unnamed: L4.1, U$11.3 (LX)
unnamed: R6.2, U$14.P$1, X1.D-
unnamed: R4.1, U$11.1 (EN), U$12.P$1
unnamed: LED2.BLUE (2), R2.1
unnamed: LED2.GREEN (3), R7.1
unnamed: LED2.RED (4), R1.1
RGB_BLUE: R2.2, U$6.P$1; also elsewhere on the board
RGB_GREEN: R7.2, U$7.P$1; also elsewhere on the board
RGB_RED: R1.2, U$5.P$1; also elsewhere on the board
RX: JP1.9 (4); also elsewhere on the board
TX: JP1.10 (3); also elsewhere on the board
UVCC: D1.ANODE, X1.VBUS
VBAT: JP2.3; also elsewhere on the board
VIN: C4.1, D1.CATHODE, JP1.12 (1), R4.2, U$11.4 (VIN)
WKP: JP1.8 (5); also elsewhere on the board

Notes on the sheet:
SMPS +3.3V Regulator
User IO
USB
Photon

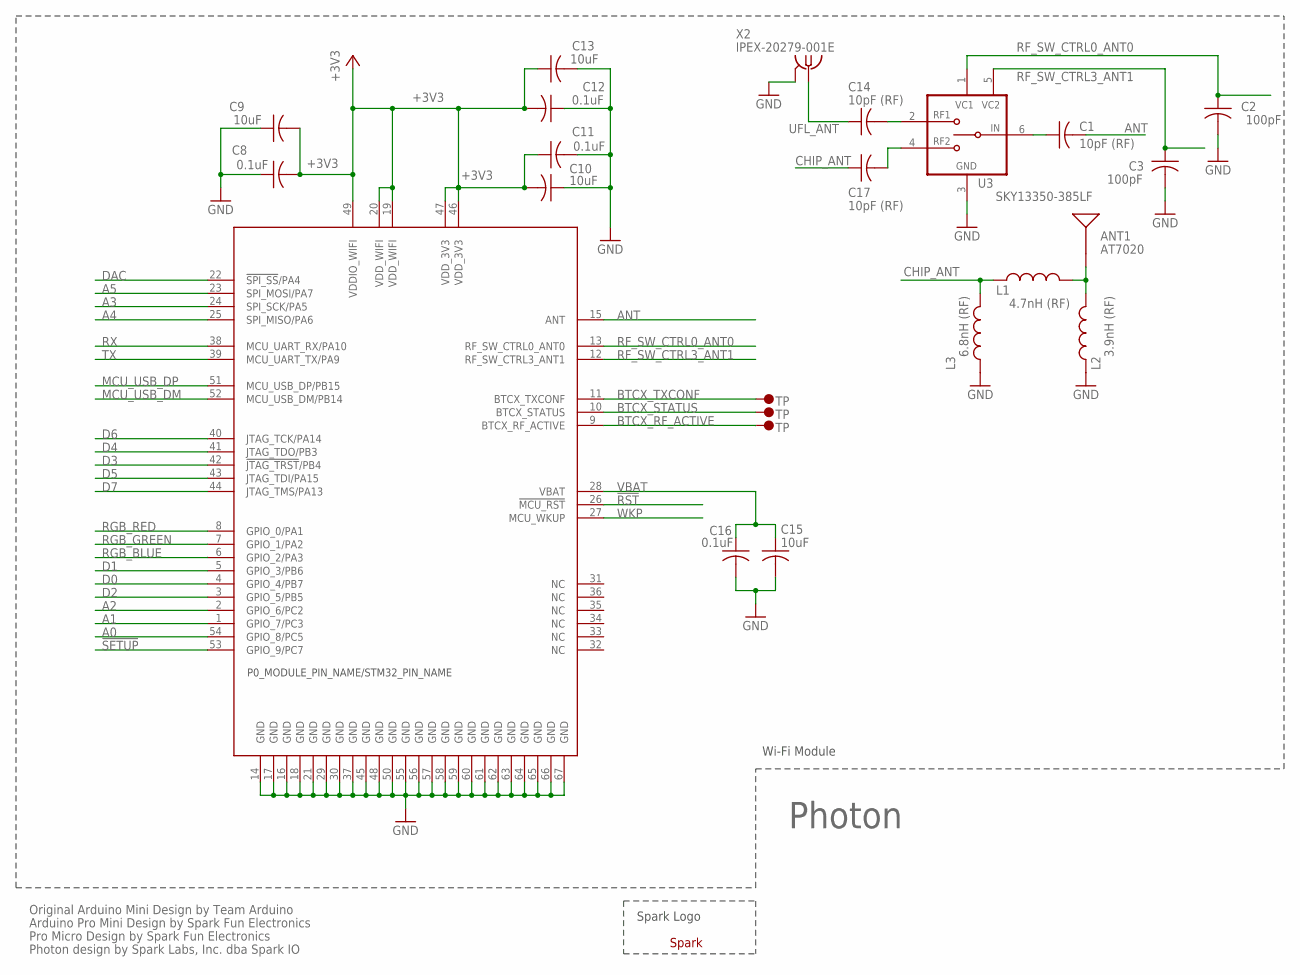
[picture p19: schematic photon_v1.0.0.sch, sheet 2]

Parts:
ANT1: AT7020
C1, C14, C17: 10pF (RF); C0201_B
C2, C3: 100pF; C0402_B
C8, C11, C12, C16: 0.1uF; C0402_B
C9, C10, C13, C15: 10uF; C0603_B
L1: 4.7nH (RF); L0402_B
L2: 3.9nH (RF); L0402_B
L3: 6.8nH (RF); L0402_B
U1: WM-N-BM-09
U3: SKY13350-385LF; XFDFN-6
U$2: SPARK_LOGO2
U$8, U$9, U$10: TP1; TP35_BOT
X2: IPEX-20279-001E

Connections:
!RST: U1.26 (!MCU_RST); also elsewhere on the board
!SETUP: U1.53 (GPIO_9/PC7); also elsewhere on the board
+3V3: C8.2, C9.2, C10.2, C11.1, C12.2, C13.1, U1.19 (VDD_WIFI), U1.20 (VDD_WIFI), U1.46 (VDD_3V3), U1.47 (VDD_3V3), U1.49 (VDDIO_WIFI); also elsewhere on the board
A0: U1.54 (GPIO_8/PC5); also elsewhere on the board
A1: U1.1 (GPIO_7/PC3); also elsewhere on the board
A2: U1.2 (GPIO_6/PC2); also elsewhere on the board
A3: U1.24 (SPI_SCK/PA5); also elsewhere on the board
A4: U1.25 (SPI_MISO/PA6); also elsewhere on the board
A5: U1.23 (SPI_MOSI/PA7); also elsewhere on the board
ANT: C1.2, U1.15 (ANT)
BTCX_RF_ACTIVE: U1.9 (BTCX_RF_ACTIVE), U$10.P$1
BTCX_STATUS: U1.10 (BTCX_STATUS), U$9.P$1
BTCX_TXCONF: U1.11 (BTCX_TXCONF), U$8.P$1
CHIP_ANT: C17.1, L1.1, L3.2
D0: U1.4 (GPIO_4/PB7); also elsewhere on the board
D1: U1.5 (GPIO_3/PB6); also elsewhere on the board
D2: U1.3 (GPIO_5/PB5); also elsewhere on the board
D3: U1.42 (!JTAG_TRST!/PB4); also elsewhere on the board
D4: U1.41 (JTAG_TDO/PB3); also elsewhere on the board
D5: U1.43 (JTAG_TDI/PA15); also elsewhere on the board
D6: U1.40 (JTAG_TCK/PA14); also elsewhere on the board
D7: U1.44 (JTAG_TMS/PA13); also elsewhere on the board
DAC: U1.22 (!SPI_SS!/PA4); also elsewhere on the board
GND: C2.2, C3.2, C8.1, C9.1, C10.1, C11.2, C12.1, C13.2, C15.2, C16.2, L2.1, L3.1, U1.14 (GND), U1.16 (GND), U1.17 (GND), U1.18 (GND), U1.21 (GND), U1.29 (GND), U1.30 (GND), U1.37 (GND), U1.45 (GND), U1.48 (GND), U1.50 (GND), U1.55 (GND), U1.56 (GND), U1.57 (GND), U1.58 (GND), U1.59 (GND), U1.60 (GND), U1.61 (GND), U1.62 (GND), U1.63 (GND), U1.64 (GND), U1.65 (GND), U1.66 (GND), U1.67 (GND), U3.3 (GND), X2.2@1 (GND), X2.2@2 (GND); also elsewhere on the board
MCU_USB_DM: U1.52 (MCU_USB_DM/PB14); also elsewhere on the board
MCU_USB_DP: U1.51 (MCU_USB_DP/PB15); also elsewhere on the board
unnamed: ANT1.1, L1.2, L2.2
unnamed: C1.1, U3.6 (IN)
unnamed: C14.2, U3.2 (RF1)
unnamed: C17.2, U3.4 (RF2)
RF_SW_CTRL0_ANT0: C2.1, U1.13 (RF_SW_CTRL0_ANT0), U3.1 (VC1)
RF_SW_CTRL3_ANT1: C3.1, U1.12 (RF_SW_CTRL3_ANT1), U3.5 (VC2)
RGB_BLUE: U1.6 (GPIO_2/PA3); also elsewhere on the board
RGB_GREEN: U1.7 (GPIO_1/PA2); also elsewhere on the board
RGB_RED: U1.8 (GPIO_0/PA1); also elsewhere on the board
RX: U1.38 (MCU_UART_RX/PA10); also elsewhere on the board
TX: U1.39 (MCU_UART_TX/PA9); also elsewhere on the board
UFL_ANT: C14.1, X2.1
VBAT: C15.1, C16.1, U1.28 (VBAT); also elsewhere on the board
WKP: U1.27 (MCU_WKUP); also elsewhere on the board

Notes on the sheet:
Original Arduino Mini Design by Team Arduino
Arduino Pro Mini Design by Spark Fun Electronics
Pro Micro Design by Spark Fun Electronics
Photon design by Spark Labs, Inc. dba Spark IO
Photon
Wi-Fi Module
Spark Logo

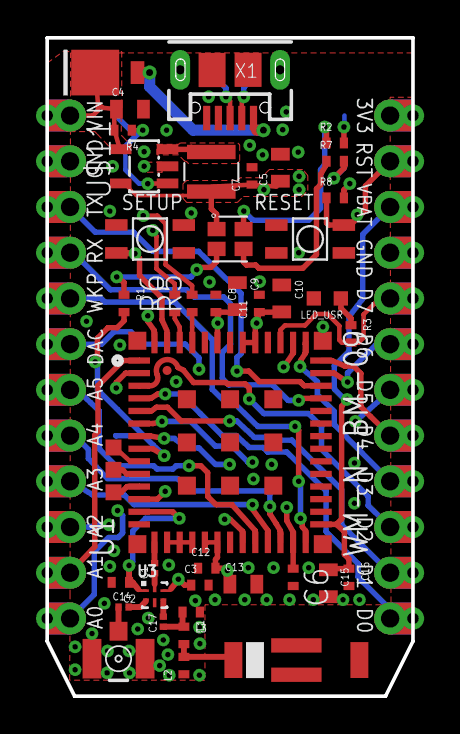
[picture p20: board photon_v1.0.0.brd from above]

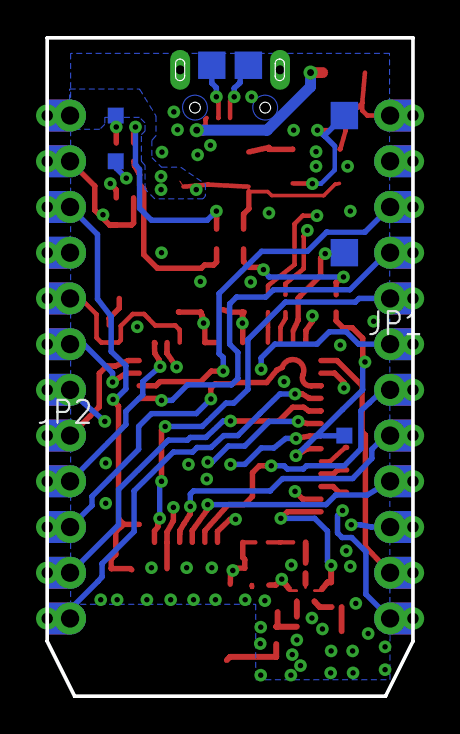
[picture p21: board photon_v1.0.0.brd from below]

Board: 4 copper layers, 20.3 x 36.6 mm, 54 parts (5 on the bottom side), 50 nets.

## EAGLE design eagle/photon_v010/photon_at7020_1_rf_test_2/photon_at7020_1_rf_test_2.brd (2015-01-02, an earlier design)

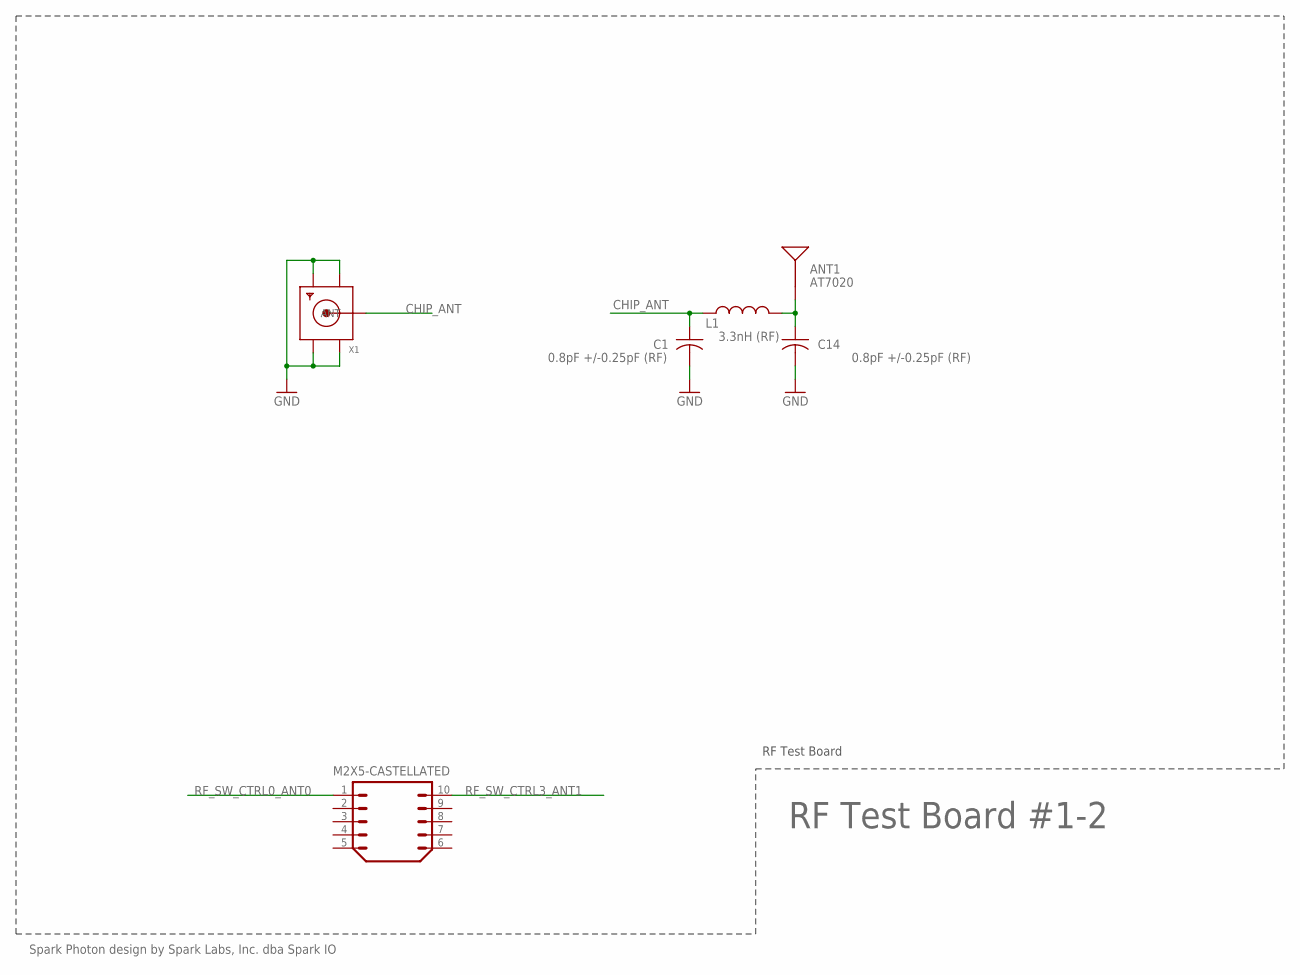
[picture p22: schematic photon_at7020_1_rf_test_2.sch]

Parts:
ANT1: AT7020
C1, C14: 0.8pF +/-0.25pF (RF); C0402_B
L1: 3.3nH (RF); L0402_B
M2X5-CASTELLATED: M2X5; 2X5-CASTELLATED
X1: SMACONNECTOR_EDGE; SMA_EDGELAUNCH

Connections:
CHIP_ANT: C1.1, L1.1, X1.P (ANT)
GND: C1.2, C14.2, X1.GND@1 (GND4), X1.GND@2 (GND3), X1.GND@3 (GND2), X1.GND@4 (GND1)
unnamed: ANT1.1, C14.1, L1.2
RF_SW_CTRL0_ANT0: M2X5-CASTELLATED.1
RF_SW_CTRL3_ANT1: M2X5-CASTELLATED.10

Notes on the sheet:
Spark Photon design by Spark Labs, Inc. dba Spark IO
RF Test Board #1-2
RF Test Board

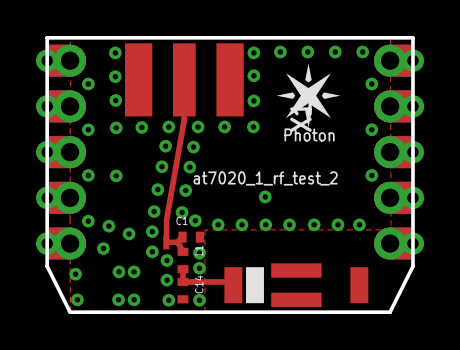
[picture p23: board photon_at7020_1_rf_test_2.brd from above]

Board: 4 copper layers, 20.3 x 15.2 mm, 6 parts (0 on the bottom side), 3 nets.

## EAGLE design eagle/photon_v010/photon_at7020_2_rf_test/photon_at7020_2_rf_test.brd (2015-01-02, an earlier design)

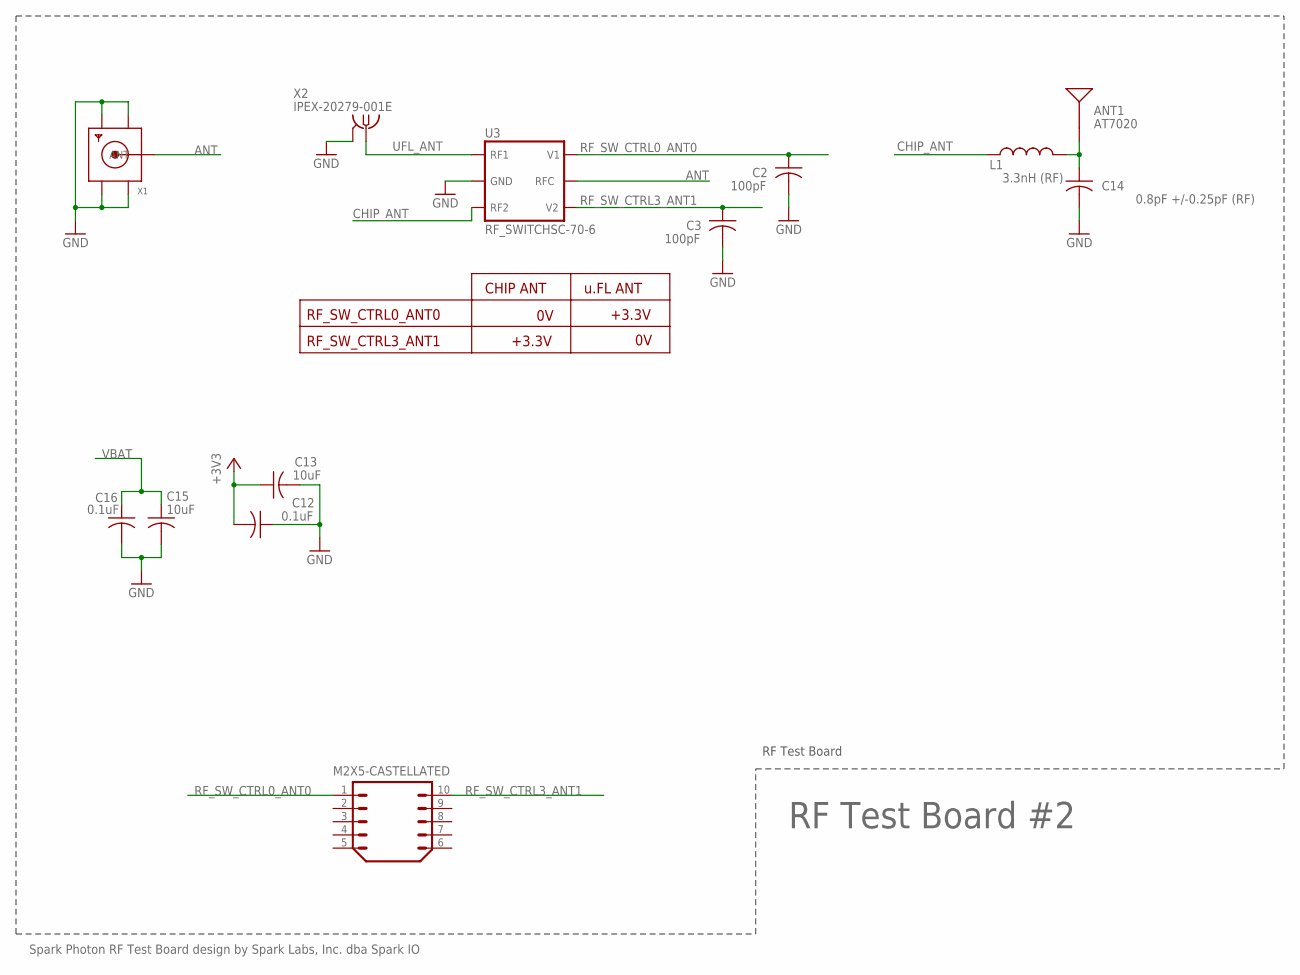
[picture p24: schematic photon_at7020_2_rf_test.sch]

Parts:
ANT1: AT7020
C2, C3: 100pF; C0402_B
C12, C16: 0.1uF; C0402_B
C13, C15: 10uF; C0402_B
C14: 0.8pF +/-0.25pF (RF); C0402_B
L1: 3.3nH (RF); L0402_B
M2X5-CASTELLATED: M2X5; 2X5-CASTELLATED
U3: RF_SWITCHSC-70-6; SC70-6
X1: SMACONNECTOR_EDGE; SMA_EDGELAUNCH
X2: IPEX-20279-001E

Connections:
+3V3: C12.2, C13.1
ANT: U3.5 (RFC), X1.P (ANT)
CHIP_ANT: L1.1, U3.3 (RF2)
GND: C2.2, C3.2, C12.1, C13.2, C14.2, C15.2, C16.2, U3.2 (GND), X1.GND@1 (GND4), X1.GND@2 (GND3), X1.GND@3 (GND2), X1.GND@4 (GND1), X2.2@1 (GND), X2.2@2 (GND)
unnamed: ANT1.1, C14.1, L1.2
RF_SW_CTRL0_ANT0: C2.1, M2X5-CASTELLATED.1, U3.6 (V1)
RF_SW_CTRL3_ANT1: C3.1, M2X5-CASTELLATED.10, U3.4 (V2)
UFL_ANT: U3.1 (RF1), X2.1
VBAT: C15.1, C16.1

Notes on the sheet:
Spark Photon RF Test Board design by Spark Labs, Inc. dba Spark IO
RF Test Board #2
RF Test Board
RF_SW_CTRL0_ANT0
RF_SW_CTRL3_ANT1
+3.3V
CHIP ANT
u.FL ANT

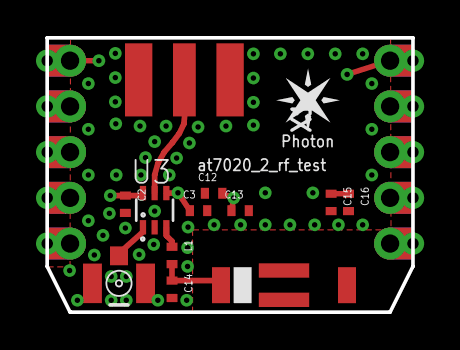
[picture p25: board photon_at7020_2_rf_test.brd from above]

Board: 4 copper layers, 20.3 x 15.2 mm, 13 parts (0 on the bottom side), 9 nets.

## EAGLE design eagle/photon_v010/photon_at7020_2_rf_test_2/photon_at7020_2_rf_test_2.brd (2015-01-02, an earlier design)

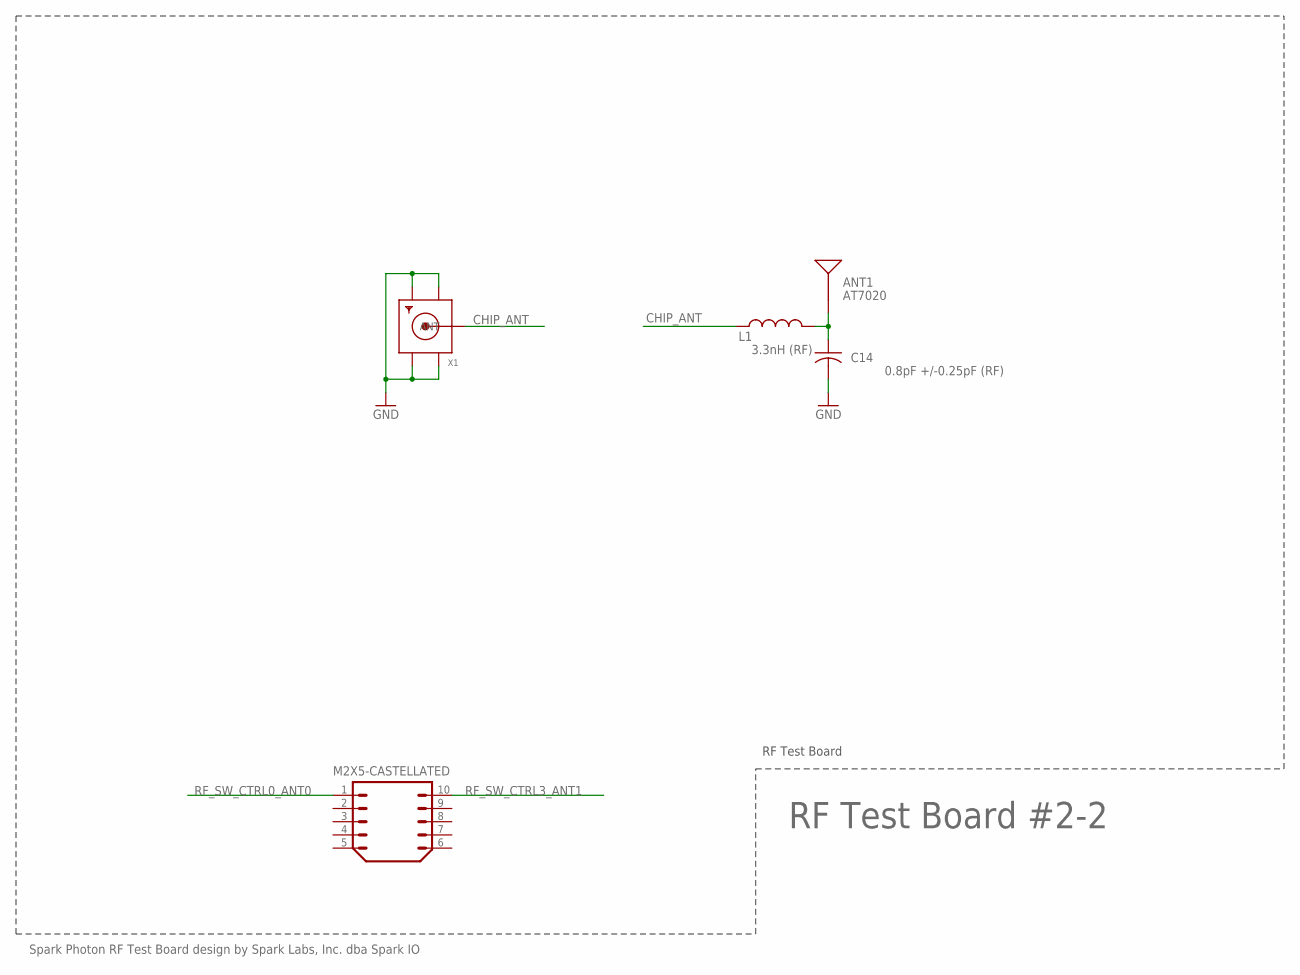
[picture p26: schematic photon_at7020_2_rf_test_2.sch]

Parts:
ANT1: AT7020
C14: 0.8pF +/-0.25pF (RF); C0402_B
L1: 3.3nH (RF); L0402_B
M2X5-CASTELLATED: M2X5; 2X5-CASTELLATED
X1: SMACONNECTOR_EDGE; SMA_EDGELAUNCH

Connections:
CHIP_ANT: L1.1, X1.P (ANT)
GND: C14.2, X1.GND@1 (GND4), X1.GND@2 (GND3), X1.GND@3 (GND2), X1.GND@4 (GND1)
unnamed: ANT1.1, C14.1, L1.2
RF_SW_CTRL0_ANT0: M2X5-CASTELLATED.1
RF_SW_CTRL3_ANT1: M2X5-CASTELLATED.10

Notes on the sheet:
Spark Photon RF Test Board design by Spark Labs, Inc. dba Spark IO
RF Test Board #2-2
RF Test Board

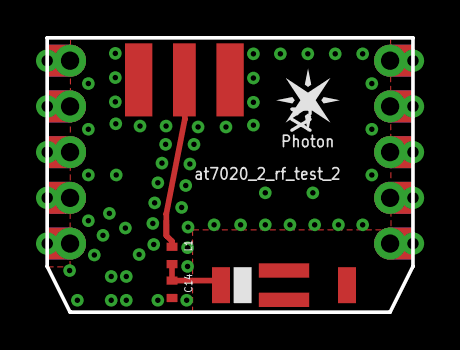
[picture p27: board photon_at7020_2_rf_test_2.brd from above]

Board: 4 copper layers, 20.3 x 15.2 mm, 5 parts (0 on the bottom side), 3 nets.

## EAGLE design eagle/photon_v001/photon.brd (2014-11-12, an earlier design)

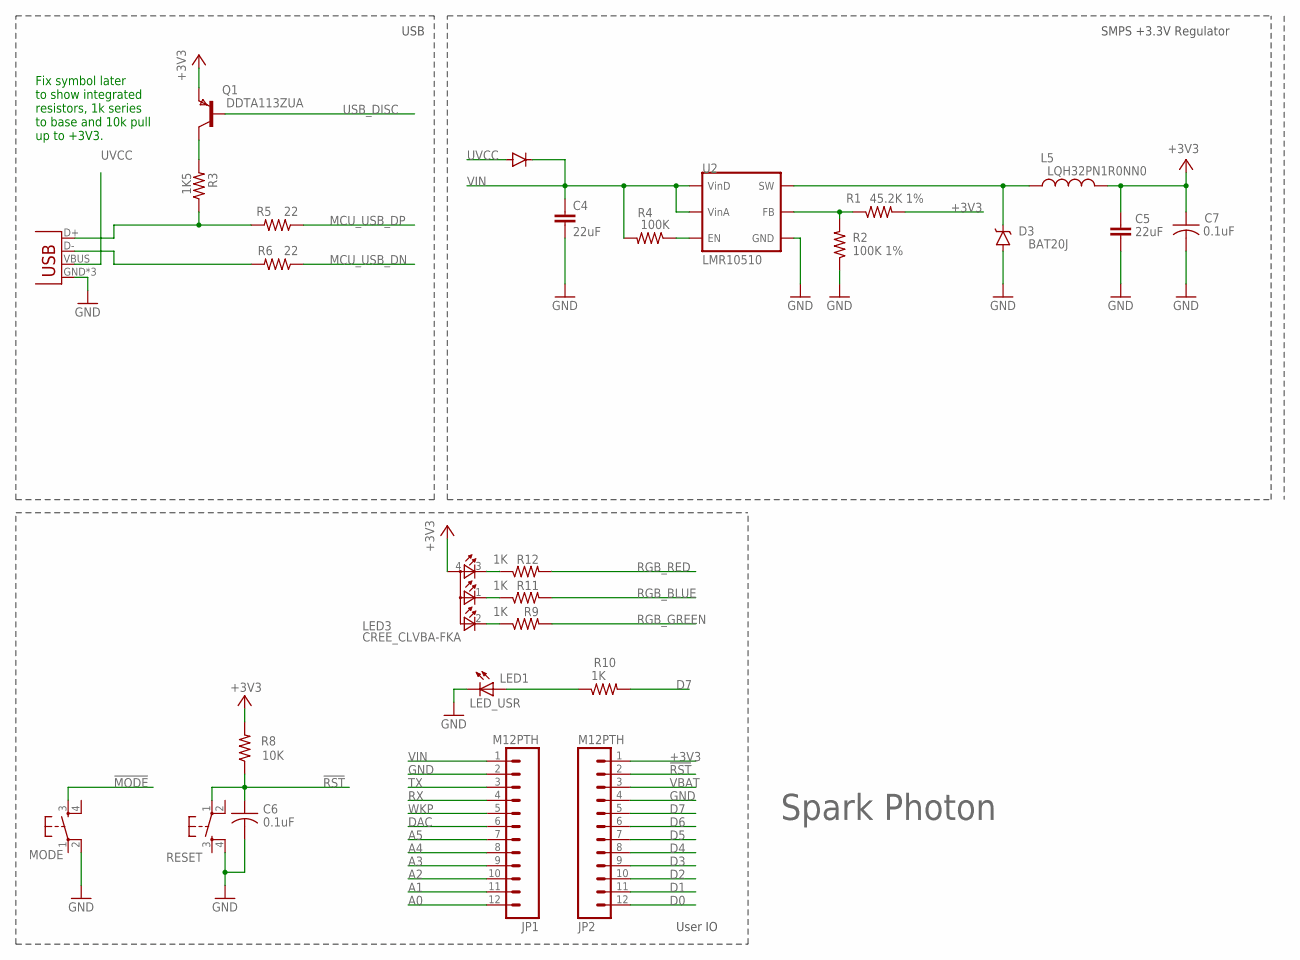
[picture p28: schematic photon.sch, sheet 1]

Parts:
C4, C5: 22uF; C0603
C6, C7: 0.1uF; C0402
D1: DIODE; DIODE-DO-220AA(SMP)
D3: BAT20J; SOD-323
JP1, JP2: M12PTH; 1X12-SMALL-PADS
L5: LQH32PN1R0NN0; 1210
LED3: CREE_CLVBA-FKA; P-LCC-4-3
LED_USR: LED0603; LED-0603
MODE: KMR211GLFS; TACTILE_SWITCH_SMD
Q1: DDTA113ZUA; SOT323
R1: 45.2K 1%; R0402
R2: 100K 1%; R0402
R3: 1K5; R0402
R4: 100K; R0402
R5, R6: 22; R0402
R8: 10K; R0402
R9, R10, R11, R12: 1K; R0402
RESET: KMR211GLFS; TACTILE_SWITCH_SMD
U2: LMR10510; WSON-6-PAD
X1: USB-MICROB; USB-MICROB-SLOT-HOLE

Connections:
!MODE: MODE.3; also elsewhere on the board
!RST: C6.1, JP2.2, R8.1, RESET.1; also elsewhere on the board
+3V3: C5.1, C7.1, JP2.1, L5.2, LED3.4 (A2), Q1.3 (E), R1.2, R8.2
A0: JP1.12; also elsewhere on the board
A1: JP1.11; also elsewhere on the board
A2: JP1.10; also elsewhere on the board
A3: JP1.9; also elsewhere on the board
A4: JP1.8; also elsewhere on the board
A5: JP1.7; also elsewhere on the board
D0: JP2.12; also elsewhere on the board
D1: JP2.11; also elsewhere on the board
D2: JP2.10; also elsewhere on the board
D3: JP2.9; also elsewhere on the board
D4: JP2.8; also elsewhere on the board
D5: JP2.7; also elsewhere on the board
D6: JP2.6; also elsewhere on the board
D7: JP2.5, R10.2
DAC: JP1.6; also elsewhere on the board
EN: R4.1, U2.6 (EN)
FB: R1.1, R2.2, U2.1 (FB)
GND: C4.2, C5.2, C6.2, C7.2, D3.A, JP1.2, JP2.4, LED_USR.C, MODE.2, R2.1, RESET.4, U2.2 (GND), U2.PAD (GND), X1.GND, X1.MT1 (GND), X1.MT2 (GND); also elsewhere on the board
LED1: LED_USR.A, R10.1
MCU_USB_DN: R6.1; also elsewhere on the board
MCU_USB_DP: R5.1; also elsewhere on the board
unnamed: R3.1, R5.2, X1.D+
unnamed: R6.2, X1.D-
unnamed: Q1.1 (C), R3.2
unnamed: LED3.1 (CBLUE), R11.1
unnamed: LED3.2 (CGREEN), R9.1
unnamed: LED3.3 (CRED), R12.1
RGB_BLUE: R11.2; also elsewhere on the board
RGB_GREEN: R9.2; also elsewhere on the board
RGB_RED: R12.2; also elsewhere on the board
RX: JP1.4; also elsewhere on the board
SW: D3.C, L5.1, U2.3 (SW)
TX: JP1.3; also elsewhere on the board
USB_DISC: Q1.2 (B); also elsewhere on the board
UVCC: D1.ANODE, X1.VBUS
VBAT: JP2.3; also elsewhere on the board
VIN: C4.1, D1.CATHODE, JP1.1, R4.2, U2.4 (VIND), U2.5 (VINA)
WKP: JP1.5; also elsewhere on the board

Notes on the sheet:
SMPS +3.3V Regulator
User IO
USB
Spark Photon
Fix symbol later to show integrated resistors, 1k series to base and 10k pull up to +3V3.

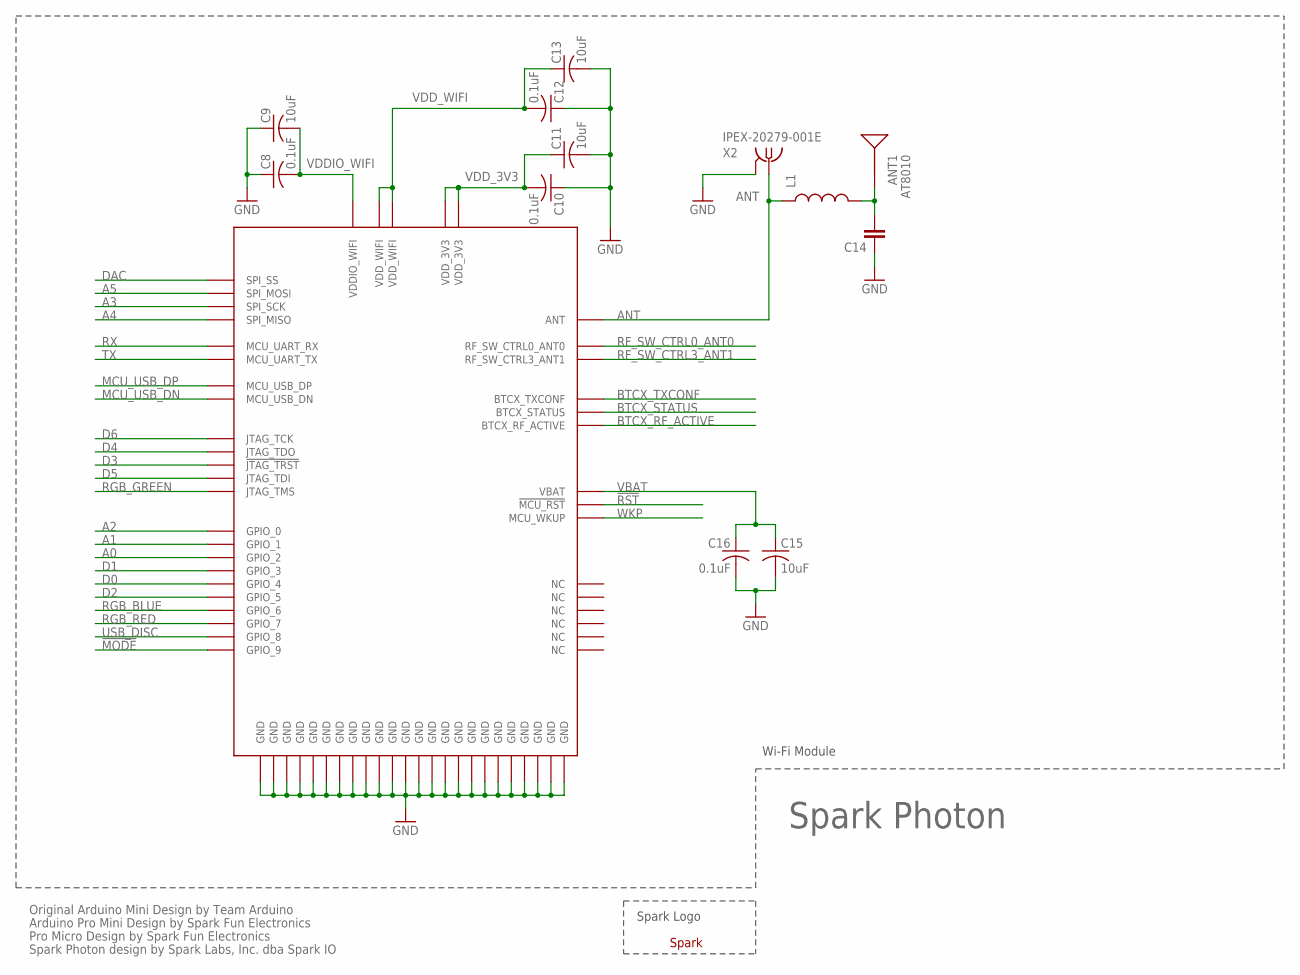
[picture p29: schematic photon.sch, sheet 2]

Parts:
ANT1: AT8010
C8, C10, C12, C16: 0.1uF; C0402
C9, C11, C13, C15: 10uF; C0402
C14: CAP0603-CAP; 0603-CAP
L1: INDUCTOR-SPARKFUN0603; 0603
U1: WM-N-BM-09
U$2: SPARK_LOGO2
X2: IPEX-20279-001E

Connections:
!MODE: U1.P$53 (GPIO_9); also elsewhere on the board
!RST: U1.P$26 (!MCU_RST); also elsewhere on the board
A0: U1.P$6 (GPIO_2); also elsewhere on the board
A1: U1.P$7 (GPIO_1); also elsewhere on the board
A2: U1.P$8 (GPIO_0); also elsewhere on the board
A3: U1.P$24 (SPI_SCK); also elsewhere on the board
A4: U1.P$25 (SPI_MISO); also elsewhere on the board
A5: U1.P$23 (SPI_MOSI); also elsewhere on the board
ANT: L1.1, U1.P$15 (ANT), X2.1
BTCX_RF_ACTIVE: U1.P$9 (BTCX_RF_ACTIVE)
BTCX_STATUS: U1.P$10 (BTCX_STATUS)
BTCX_TXCONF: U1.P$11 (BTCX_TXCONF)
D0: U1.P$4 (GPIO_4); also elsewhere on the board
D1: U1.P$5 (GPIO_3); also elsewhere on the board
D2: U1.P$3 (GPIO_5); also elsewhere on the board
D3: U1.P$42 (!JTAG_TRST); also elsewhere on the board
D4: U1.P$41 (JTAG_TDO); also elsewhere on the board
D5: U1.P$43 (JTAG_TDI); also elsewhere on the board
D6: U1.P$40 (JTAG_TCK); also elsewhere on the board
DAC: U1.P$22 (SPI_SS); also elsewhere on the board
GND: C8.1, C9.1, C10.1, C11.2, C12.1, C13.2, C14.1, C15.2, C16.2, U1.P$14 (GND), U1.P$16 (GND), U1.P$17 (GND), U1.P$18 (GND), U1.P$21 (GND), U1.P$29 (GND), U1.P$30 (GND), U1.P$37 (GND), U1.P$45 (GND), U1.P$48 (GND), U1.P$50 (GND), U1.P$55 (GND), U1.P$56 (GND), U1.P$57 (GND), U1.P$58 (GND), U1.P$59 (GND), U1.P$60 (GND), U1.P$61 (GND), U1.P$62 (GND), U1.P$63 (GND), U1.P$64 (GND), U1.P$65 (GND), U1.P$66 (GND), U1.P$67 (GND), X2.2@1 (GND), X2.2@2 (GND); also elsewhere on the board
MCU_USB_DN: U1.P$52 (MCU_USB_DN); also elsewhere on the board
MCU_USB_DP: U1.P$51 (MCU_USB_DP); also elsewhere on the board
unnamed: ANT1.SIG, C14.2, L1.2
RF_SW_CTRL0_ANT0: U1.P$13 (RF_SW_CTRL0_ANT0)
RF_SW_CTRL3_ANT1: U1.P$12 (RF_SW_CTRL3_ANT1)
RGB_BLUE: U1.P$2 (GPIO_6); also elsewhere on the board
RGB_GREEN: U1.P$44 (JTAG_TMS); also elsewhere on the board
RGB_RED: U1.P$1 (GPIO_7); also elsewhere on the board
RX: U1.P$38 (MCU_UART_RX); also elsewhere on the board
TX: U1.P$39 (MCU_UART_TX); also elsewhere on the board
USB_DISC: U1.P$54 (GPIO_8); also elsewhere on the board
VBAT: C15.1, C16.1, U1.P$28 (VBAT); also elsewhere on the board
VDDIO_WIFI: C8.2, C9.2, U1.P$49 (VDDIO_WIFI)
VDD_3V3: C10.2, C11.1, U1.P$46 (VDD_3V3), U1.P$47 (VDD_3V3)
VDD_WIFI: C12.2, C13.1, U1.P$19 (VDD_WIFI), U1.P$20 (VDD_WIFI)
WKP: U1.P$27 (MCU_WKUP); also elsewhere on the board

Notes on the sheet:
Original Arduino Mini Design by Team Arduino
Arduino Pro Mini Design by Spark Fun Electronics
Pro Micro Design by Spark Fun Electronics
Spark Photon design by Spark Labs, Inc. dba Spark IO
Spark Photon
Wi-Fi Module
Spark Logo



Board: 4 copper layers, 20.3 x 35.6 mm, 41 parts (2 on the bottom side), 46 nets.

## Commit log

2014-12-04 updated smd footprint library for the photon
2014-12-26 updated pinmap and added extra documentation for P0 module
    [photon-pinmap.xlsx]
2015-01-02 new directory structure
    [photon.brd, photon.sch]
2015-01-02 added two new photon designs with rf test boards
    [photon_at7020_1.brd, photon_at7020_1.sch, photon_at7020_1_rf_test.brd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]
2015-01-02 file cleanup
    [photon.GBL, photon.GBO, photon.GBP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]
2015-01-02 versioning bom v001
    [photon-bom-v001.xlsx]
2015-01-02 versioning pinmap v010
    [photon-pinmap-v010.xlsx]
2015-01-16 updated RGB LED datasheet to 2mm version
2015-01-24 added photon-bom-v010.xlsx
    [photon-bom-v001.xlsx, photon-bom-v010.xlsx]
2015-01-24 added pdfs of v010 schematics
2015-01-28 updated L5 desc and size and C4, C5 package size
    [photon-bom-v010.xlsx]
2015-02-20 Updated 2mm RGB LED and castellated header soldermask
2015-03-02 added P1 / WM-N-BM-14 pinmap and EAGLE library files
    [p1-pinmap.xlsx]
2015-03-23 updated photon pinmap
    [photon-pinmap-v010.xlsx, photon-pinmap.xlsx]
2015-03-27 Photon v019 design files added
    [photon_v019.brd, photon_v019.sch, photon_v019_fab_english.xlsx]
2015-03-27 added v019 bom
    [photon-bom-v019.xlsx]
2015-03-31 corrected bom qty for 10pF caps (3x)
    [photon-bom-v019.xlsx]
2015-04-09 updated P1 pinmap
    [p1-pinmap.xlsx]
2015-05-08 Added PHOTON and PHOTON_SMD devices to Spark.lbr
2015-06-07 Updated WM-N-BM-14 device (P1 Module)
2015-06-07 Photon v1.0.0 design files
    [photon-bom-v1.0.0.xlsx, photon_v1.0.0.brd, photon_v1.0.0.sch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]
2015-06-18 updated pinmap
    [p1-pinmap.xlsx, photon-pinmap.xlsx]

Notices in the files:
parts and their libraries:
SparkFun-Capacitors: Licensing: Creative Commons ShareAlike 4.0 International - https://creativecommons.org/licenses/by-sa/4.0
